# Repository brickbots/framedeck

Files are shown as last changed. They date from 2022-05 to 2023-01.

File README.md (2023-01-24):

# framedeck

A Cyberdeck built with the framework mainboard.  

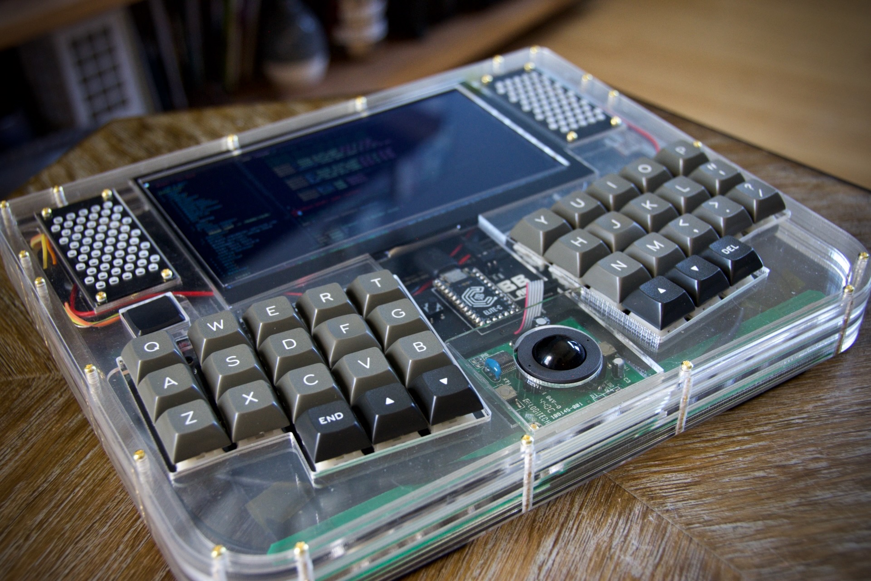
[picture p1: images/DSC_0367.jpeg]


[Framework](https://frame.work) has 
created a really slick, fully user servicable, laptop and have recently started selling the 
[mainboard](https://frame.work/marketplace/mainboards) as a SBC for general 
use.  To better support folks who may want to integrate it into their projects, they are also 
releasing [technical documentation](https://github.com/FrameworkComputer/Mainboard) including 
pinouts, cad models and other resources.

As they were preparing this documentation release, they emailed me to see if I'd be interested
in a collaboration of sorts.  They would provide one of their laptops and some additional modules
for me to build something unique with the only condition being that I released the designs 
for public use.  So here we are!

The mainboard is a great little unit, being a full Intel based system on a single board with 
great storage and memory expansion, decent on-board graphics and full power management.  Since
it was designed to fit into the laptop first and foremost, some of the connectors are fairly
specialized, but with the pinouts available there are a lot of opportunities for expansion. The
board also has four standard USB-C ports which provide many possibilities without even trying
any of the other on-board connectors.

That's all to say that when they reached out and explained thier plans and offered to let 
me play with one, I jumped at the chance and this is what I came up with after some experimentation.

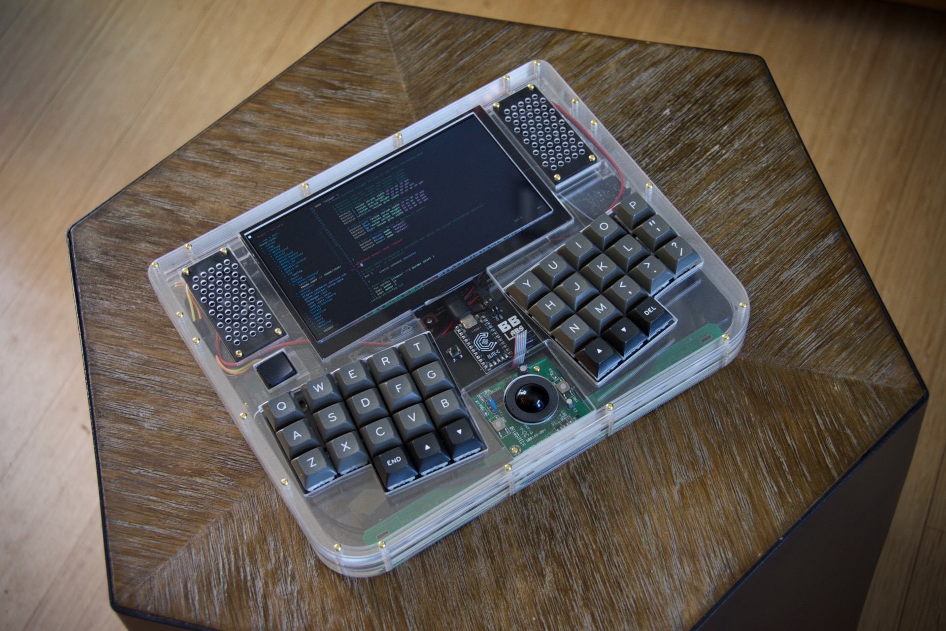
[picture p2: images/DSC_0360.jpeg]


It's my take on the slab style computers that were somewhat popular before the world settled
on clamshell designs for portable computers.  I really wanted a 
[TRS-80 model 100](https://en.wikipedia.org/wiki/TRS-80_Model_100) when I was young so this
sort of design was a big influence.

To complete the unit I added battery from the framework laptop, custom mechanical keyboard, wifi card, 
ssd storage, 16gb of memory, 7" IPS display and some speakers in the hopes of making a fairly useful 
computer.  I ended up using the mainboard with their battery rather than roll my own power solution as
it has solid capacity and is already desinged to work with the onboard power management.  For
other uses the mainboard can be powered via USB-C, so a solid powerbank would provide plenty 
of runtime or it can run off any USB-C power brick for stationary use.

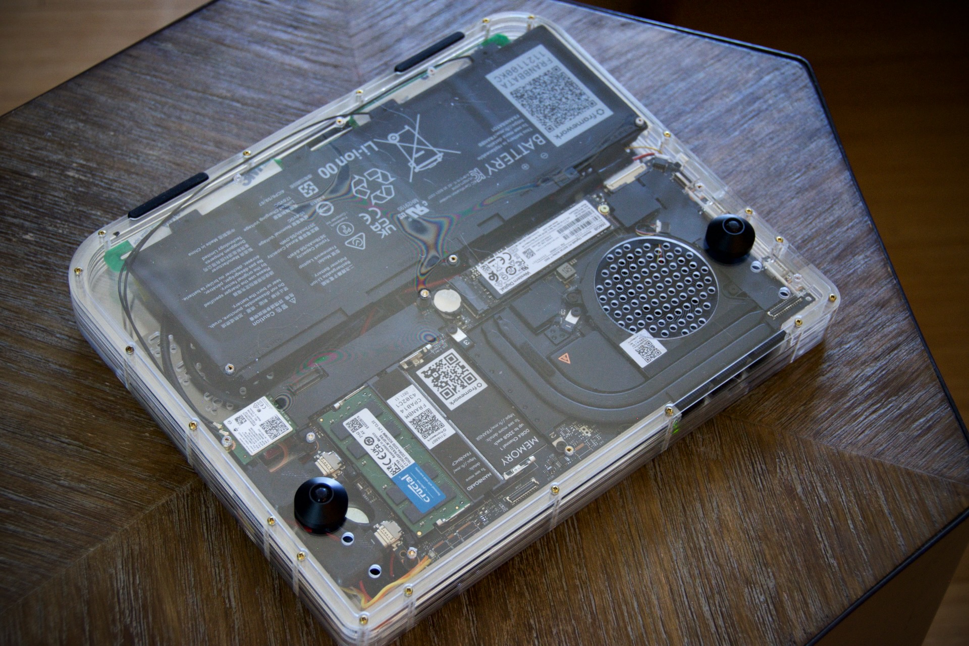
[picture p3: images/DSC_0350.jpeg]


For the case, I wanted something interesting that showed off the mainboard, custom keyboard PCB and 
just looked unusual... so clear acrylic and brass won the day!  I thought about 3d printing, and 
I could have done it in several sections, but building the unit up with layers of laser-cut acrylic 
offered some interesting challenges and opportunities.  

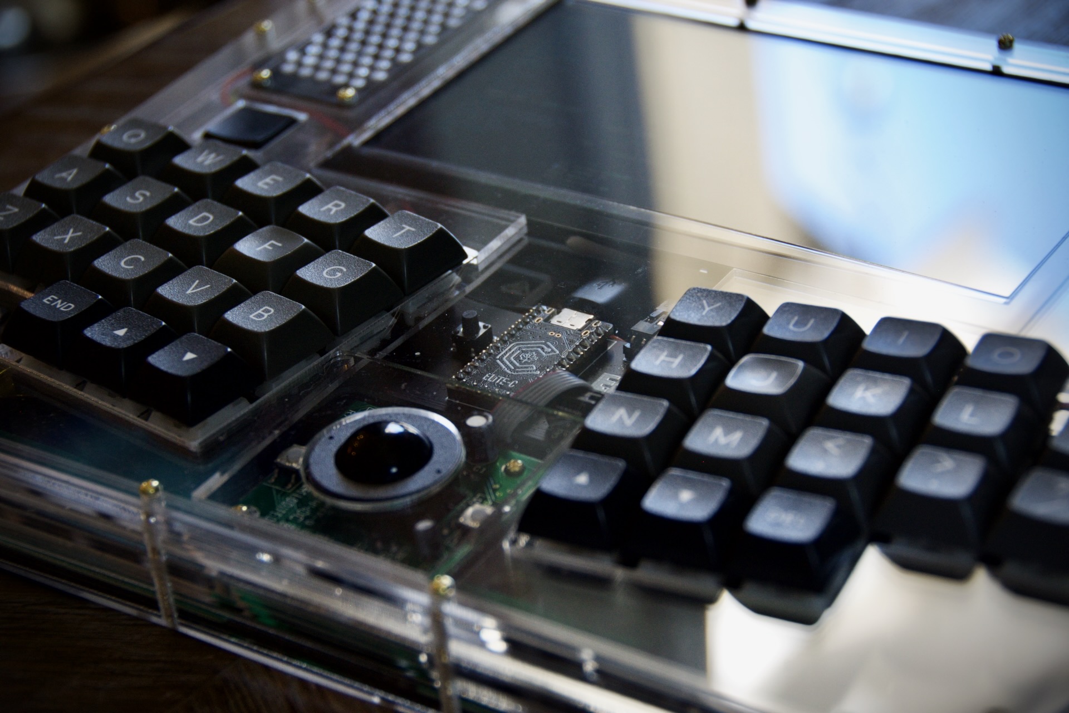
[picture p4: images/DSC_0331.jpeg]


Consider this repo a sort of 'guided tour' to give some inspiration and show what might be done with the
framework mainboard.  I'll highlight some things that I think are interesting, or that were tricky, but 
it's not meant to be a comprehensive guide so all the normal caveats apply if you
want to dive in and build something based off this material.  I'm including all of
my design files for reference, but there are lots of details of the build I probably won't cover.  
If you want to build one, or something similar, feel free to reach out and I'd be happy to answer
and questions or provide advice.

* [Build Tour](docs/build_tour.md)
* [Parts List](docs/parts.md)
* [Case Layers](case/layers.md)
* [3d Printed Bits](printed_parts/bits.md)
* [What's with that keyboard?](docs/keyboard.md)

## Copyright and License

Copyright (c) 2022 Richard Sutherland. All rights reserved.

All files are licensed under MIT license or [CC BY-SA 4.0](https://creativecommons.org/licenses/by-sa/4.0/), see the [LICENSE](LICENSE) for more information.

<a href='https://ko-fi.com/brickbots' target='_blank'>Buy Me a Coffee at ko-fi.com

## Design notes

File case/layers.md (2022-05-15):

# framedeck - layer guide

The acrylic case is built in layers.  I've included DXF files suitable
for laser printing, they use MM as units.  Layers are built in roughly
alphabetical order from the top down, but some layers appear twice and 
may be different thicknesses.

Around the edge of all the layers (except the last one) are holes to 
hold the whole sandwich together.  The A (top) and L (bottom) layers 
have holes sized for M2 screws.  The layers between have holes sized
for M2 standoffs.  You can screw into the standoffs from the top 
and bottom to secure the assembly.  You will need LONG standoffs...
I had to combine a couple to get them long enough.

The bottom two layers are held together with 3mm long M2 heat set inserts.  
Each of the bottom two layers are 1.5mm so the insert neatly joins them
together when inserted through both. They serve to secure the very bottom M 
layer to the bottom L layer and also provide fixing points for the mainboard 
and battery.

Please see this table below for full details of all the layers.  Since the 
actual thickness of cut acrylic will usually vary, you may need to add or 
remove some of the general spacer layers (E/G) or try different thicknesses.
I ended up using all of these as is, with the exception of one of the 'C' layers

## Hardware
Layer|Thickness (MM)|Notes|Image
---|---|---|---
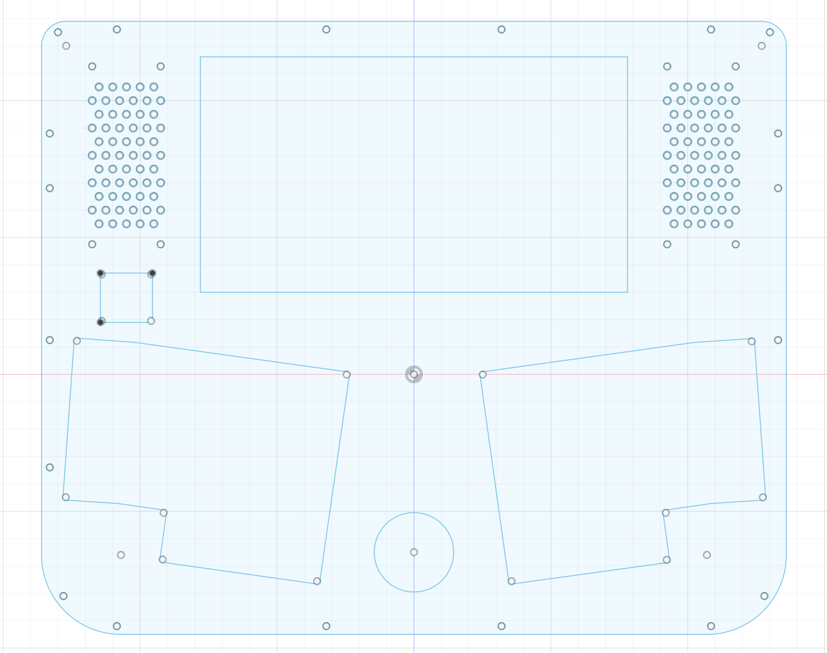
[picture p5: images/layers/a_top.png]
A Layer A
A|1.5|Top|
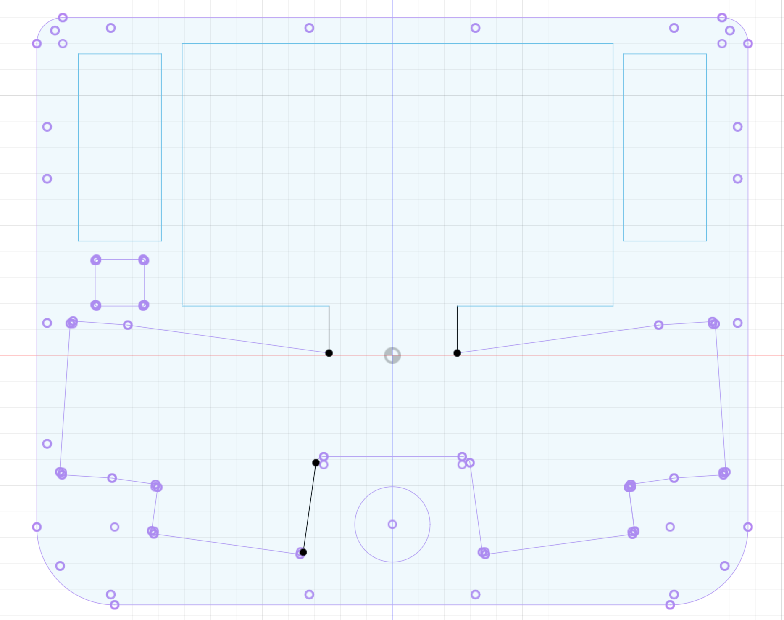
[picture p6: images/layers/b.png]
B Layer B
B|2.0||
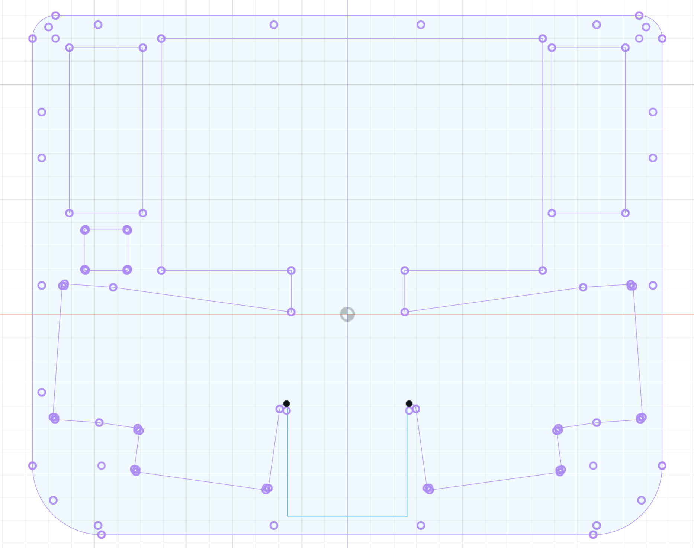
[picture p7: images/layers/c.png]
C Layer C
C (1)|1.5|C layers combined = 2.5mm|
C (2)|1.0|C layers combined = 2.5mm|C Layer C
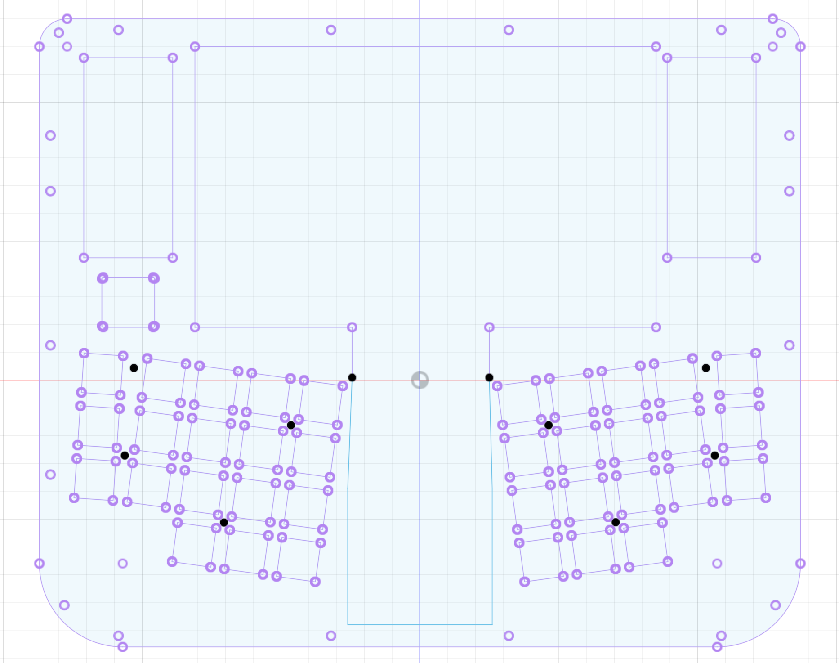
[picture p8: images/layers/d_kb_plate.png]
D Layer D
D|1.5|KB Plate|
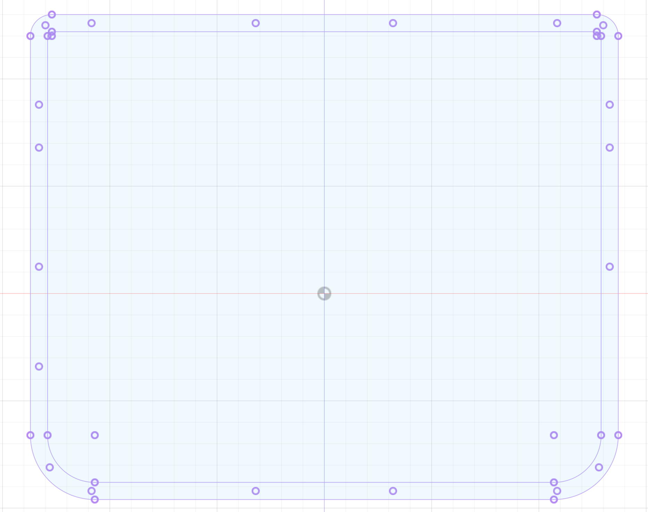
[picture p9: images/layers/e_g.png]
EG Layer E / G
E (1)|1.5| E/G Layers use same file|
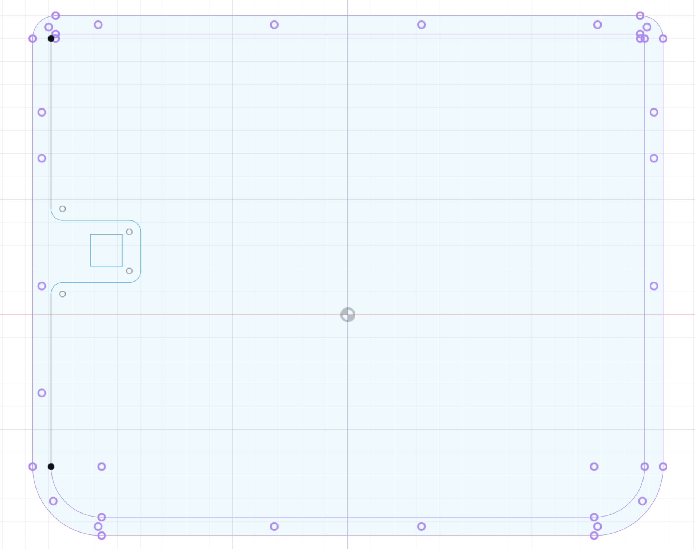
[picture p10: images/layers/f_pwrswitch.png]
F Layer F
F|1.5|Power switch|
G|3.0| E/G Layers use same file|EG Layer E / G
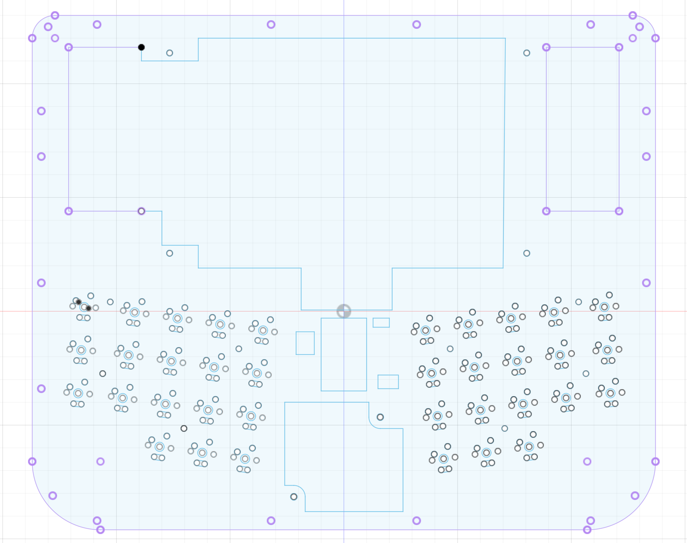
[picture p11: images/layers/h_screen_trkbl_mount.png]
H Layer H
H|3.0||
E (2)|1.5|E/G Layers use same file|EG Layer E / G
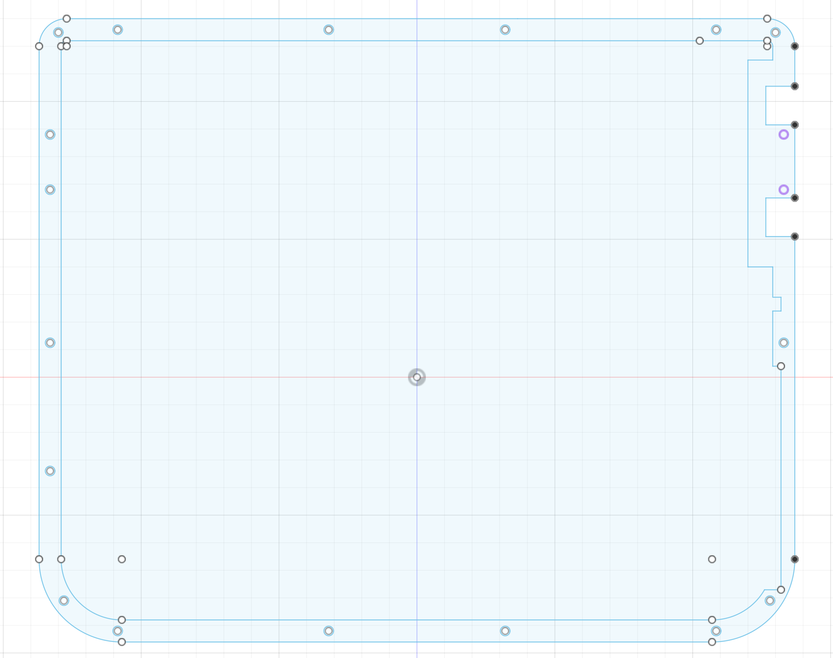
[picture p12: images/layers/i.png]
I Layer I
I|3.0||
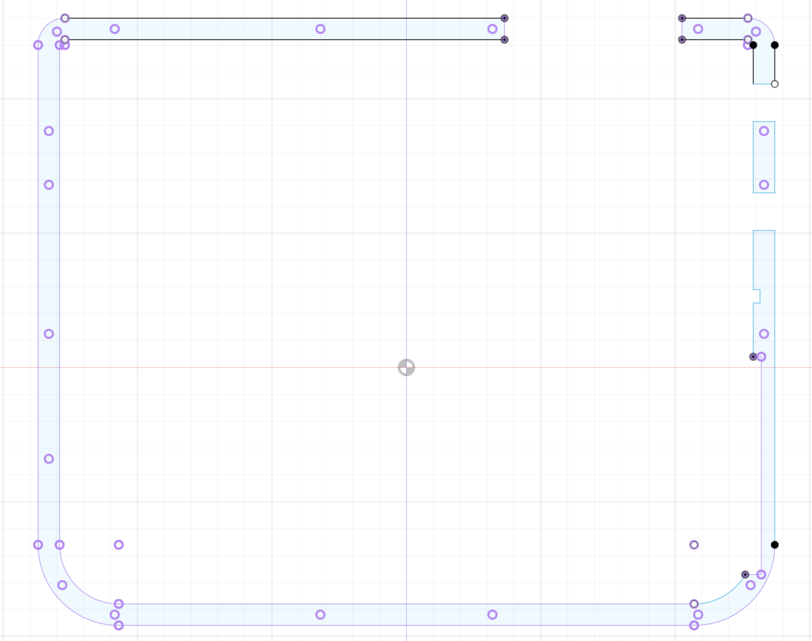
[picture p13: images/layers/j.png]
J Layer J
J (1)|2.0||
J (2)|2.0||J Layer J
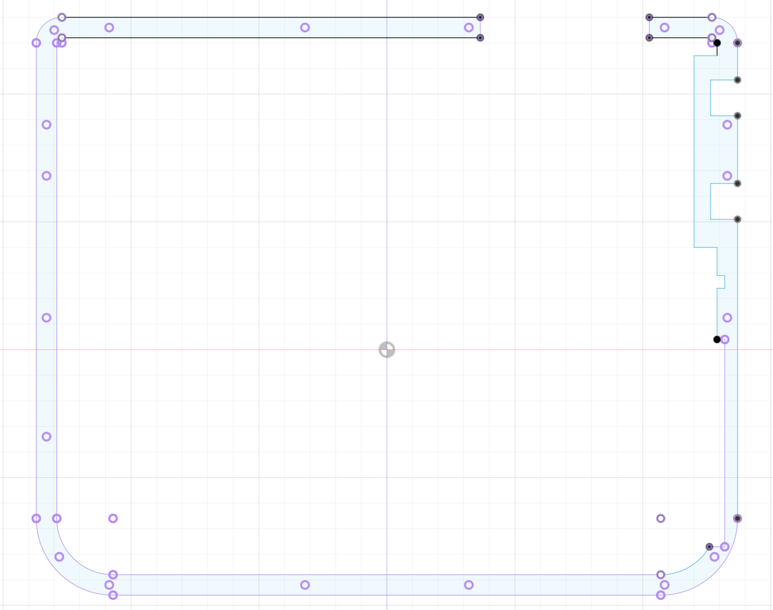
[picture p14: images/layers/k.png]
K Layer K
K|3.0||
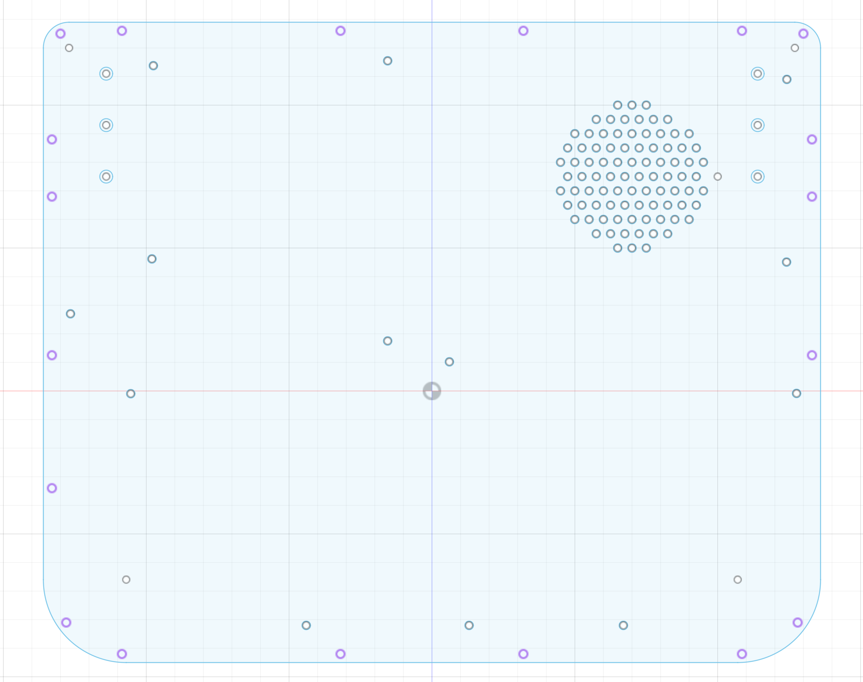
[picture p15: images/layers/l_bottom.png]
L Layer L
L|1.5|Bottom|
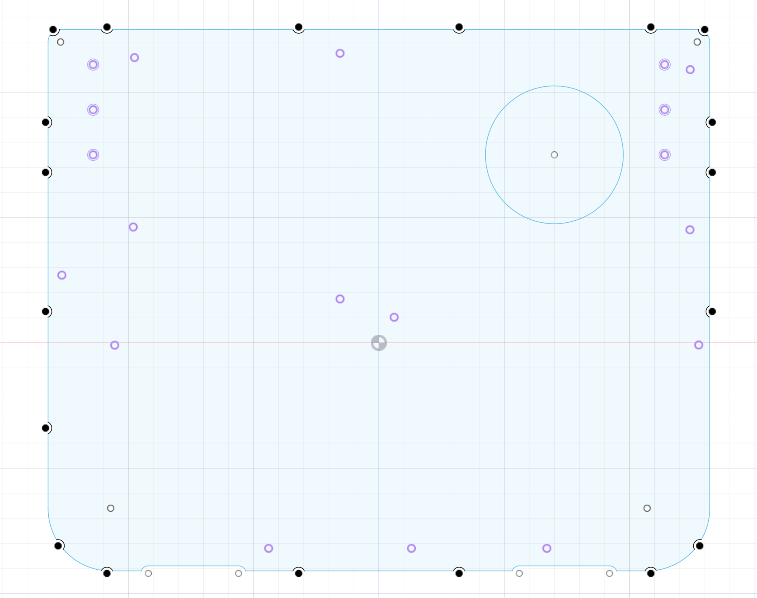
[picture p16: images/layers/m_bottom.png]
M Layer M
M|1.5|Bottom|

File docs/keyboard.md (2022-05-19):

# framedeck - keyboard

The keyboard layout used on the framedeck is something I sort of take for 
granted as it's the one I've been using for quite a while in various
forms.... but it's something that's, understandably, generated a lot of questions!

These usually boil down to either "How do you type with so few keys?" or "Where is 
the [specific key] key?".  Not only is the keyboard on the framedeck light on keys, 
the markings on the keys are not very specific.

## Physical layouts, virtual layouts and layers

Every keyboard has sort of two layouts... how the keys are arranged in space, the 
physical layout, and what each key does when you press it, the logical one.  Most
keyboards indicate what happens when you press a key with the legend on the keycap,
which is pretty handy!  

However, these legends don't often tell the full story.  The
key marked with a 'W' on your keyboard probably generates a 'w', but if you hold the
shift key it generates a 'W'.  Only one of those is probably marked on the key because
this is such a common way to arrange things... but 
sometimes, in the case of numbers, the shifted value is also indicated.  Older computers
might have even more indications for other types of key-combinations....

The general idea is that by pressing a specific key, like shift, all the other keys switch
to another 'layer' and generate something different.  This allows us to generated hundreds of 
symbols with many fewer keys.

In the extreme, you can geneate many, many symbols with very few keys :-)  Most custom 
keyboards run software which is very flexible and allows a lot of options when it comes 
to remapping keys.

## Miryoku

It's surprisingly easy to endlessly tweak the way a keyboard works once you have that 
power.  There are many discussion about finger placement and letter frequency in various
languages, but there is no empirically correct answer, so it's easy to just keep changing 
things, even if you keep the keys in the same positions.  If you also play around with 
varous physical layouts, there is even more to fiddle with.  Each one of these changes 
means some amount of re-learning... so after a year or 
so of tweaking my own layouts (physical and logical) and having to partially re-learn each 
time, I discovered [Miryoku](https://github.com/manna-harbour/miryoku).  It's a much better 
logical layout than I ever came up with and has the amazing benefit of being suported on
top of many, many (almost any!) physical layout.

This last bit was important to me as I had accumlated an embarassing amount of keyboards
and I wanted to be able to use them all without remembering what layout each had been
configured with.

Miryoku Layout

The default letter layout for Miryoku is Colmak-DH, but I configure mine with standard QWERTY. 
One day I really should switch, but for now it's working well for me.  The image above shows all
functions for all the layers, but the website has a much more digestable set of images with 
each layer on it's own. 

## Layer Tap and home-row mods

Almost all smaller keyboards use a system for accessing layers which allow these layer select 
keys (like the shift key on a standard keyboard) to be used for double duty.  If you tap these
keys they generate a specific symbol, such as space or enter, but if you hold it down and press
another key, you get the layer version of the second key.  All the thumb buttons are setup this
way and are the primary way of getting to the various layers in Miryoku, but they also do the 
heavy lifting with often used keys like space, tab, enter, esc, delete, and backspace.o

Shift, Ctrl, Alt, and Mod (Windows/Mac) keys are on the home row and are duplicated on each side
so you can hold down the 'J' key with the left hand and press any key on the right hand for the 
shifted version of that key.

The [Miryoku Docs](https://github.com/manna-harbour/miryoku/tree/master/docs/reference) do a
much better job of explaining this, so give them a read if you are interested!

If you'd like to hear more about my journey with the layout and reducing key counts, check out
[My Miryoku Journey](https://github.com/manna-harbour/miryoku/discussions/60)

Cheers!

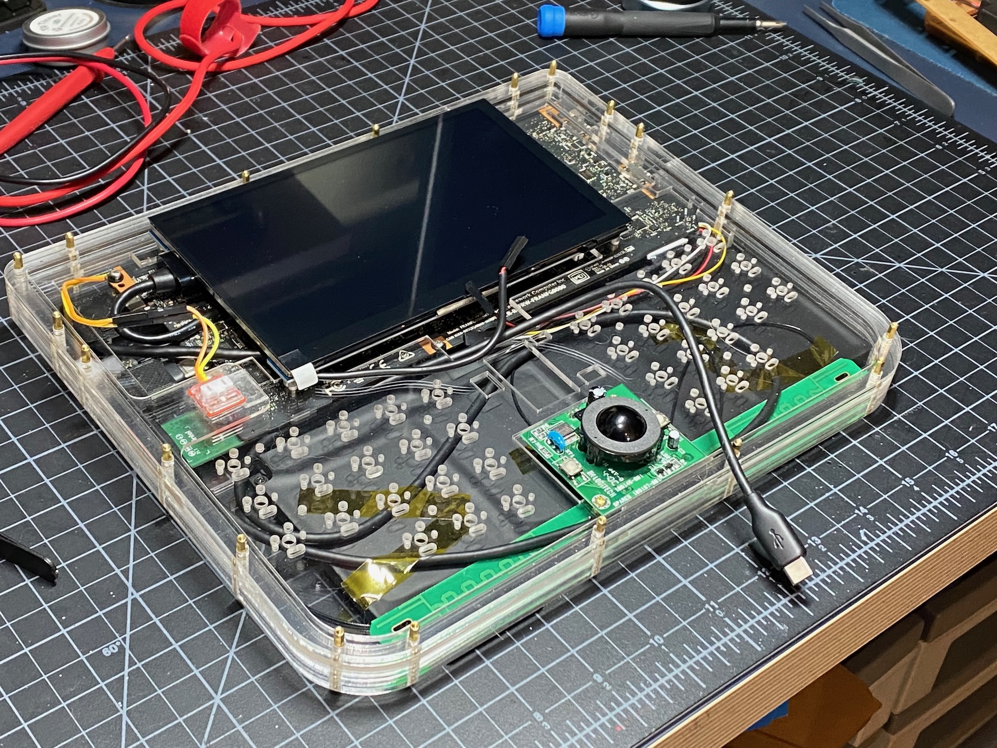
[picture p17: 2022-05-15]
images/power_switch.jpeg

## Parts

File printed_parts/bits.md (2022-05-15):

# framedeck - printed parts

Here are STL's for the M2 to mainboard adapters plus the cable enclosures for 
the right-angle USB-C hdmi and keyboard cable.

The mainboard adapaters need two for each screw to sandwich the mainboard between them.
For the right-angle adapter, you can mirror for the other half and trim to length.  I
filled mine with epoxy to serve as strain relief and hold the two halves together.

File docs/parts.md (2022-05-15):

# framedeck - Parts List

This is not a comprehensive parts list.  You'll need lots of M2 hardward, wires and 
likely some other bits to build a complete copy of the framedeck.  This list is 
more for refence of some of the specific items I selected.

## Electronics
Quantity|Item|URL
---|---|---
1|framework mainboad| https://frame.work/marketplace/mainboards
1|framework battery| https://frame.work/products/battery
1|M2 compatible Wifi board| https://frame.work/products/intel-wi-fi-6e-ax210-vpro
1|Compatible Wifi antenna| https://www.amazon.com/gp/product/B08T8F3GDT/
1|M2 compatible NVMe storage| 
1|DDR4 SO-DIMM| 
1|Logitech 161A keyboard mouse trackball board mouse board T-SBC12-CP|https://www.aliexpress.com/item/1005001942167314.html
1|7" HDMI IPS Display|https://www.amazon.com/gp/product/B08H8HZRLQ
1|USB-C to HDMI cable|https://www.amazon.com/gp/product/B083KQNHQH/
1|Set of speakers|https://www.adafruit.com/product/1669

## Keyboard
Quantity|Item|URL
---|---|---
1|Keyboard PCB| /gerbers/framedeck_kb_gerbers.zip
1|6 x 6mm x 7mm PCB Momentary Switch 4 Pin DIP|
36| MX style switches|
36| 1N4148 SMT SOD-123 Diodes|
1|Elite-C Microcontroller.  Required for extra pins|

## Misc
Quantity|Item|URL
---|---|---
2|Rubber Feet - SKUFs!| https://keeb.io/products/skuf-silicone-rubber-keyboard-feet 
2|Raised KB conical feet, M3 screws| https://www.amazon.com/gp/product/B07WRPTTBV

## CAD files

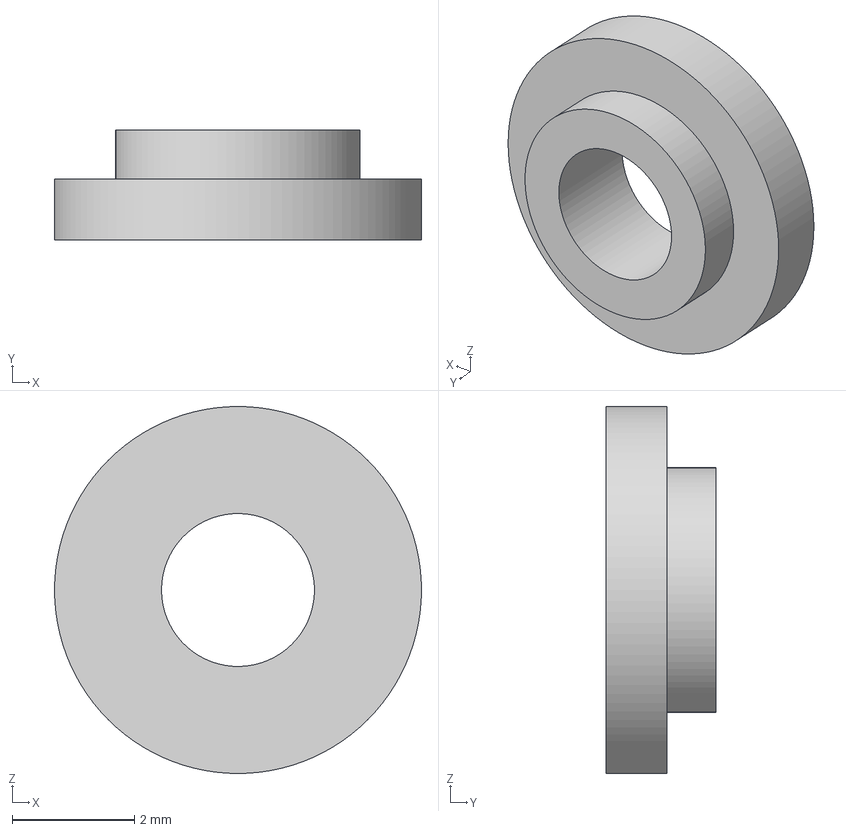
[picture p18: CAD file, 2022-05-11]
printed_parts/mainboard_mount.3mf
6.00 x 1.80 x 6.00 mm

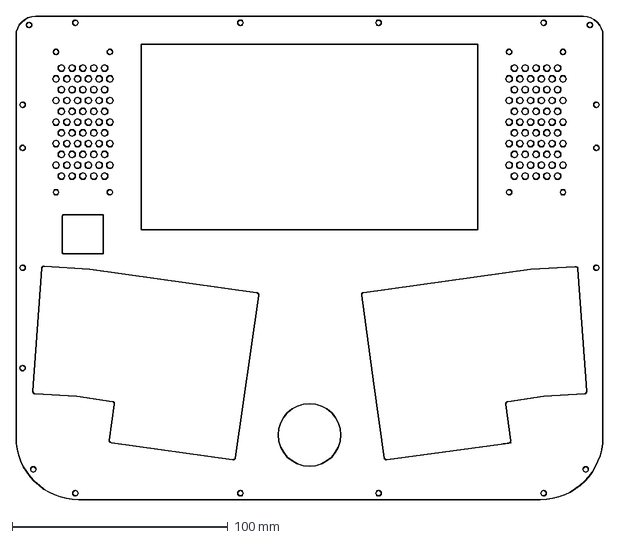
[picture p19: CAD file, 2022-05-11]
case/framedeck_case_A.dxf
272.0 x 224.0 mm

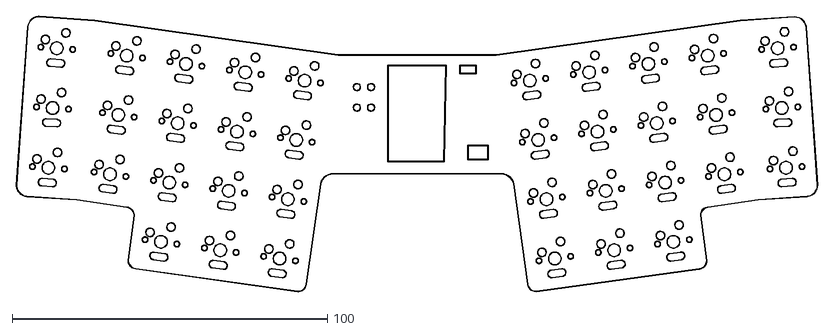
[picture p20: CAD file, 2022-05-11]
kicad/framedeck_kb/framedeck_kb-B_Adhes.dxf
254.2 x 87.3

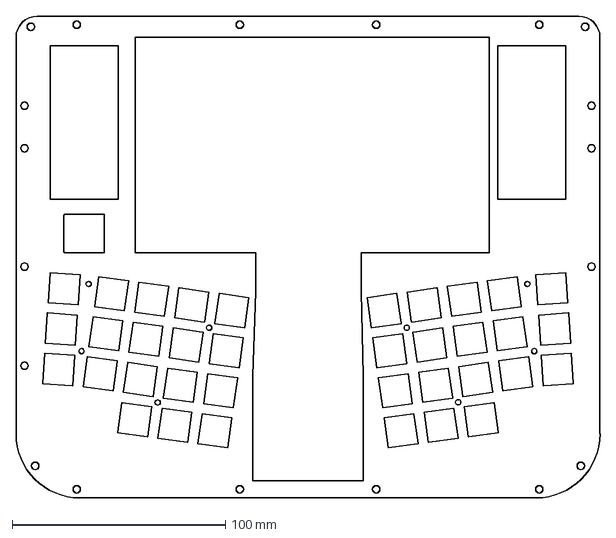
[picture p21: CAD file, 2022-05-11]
case/framedeck_case_D.dxf
274.0 x 226.0 mm

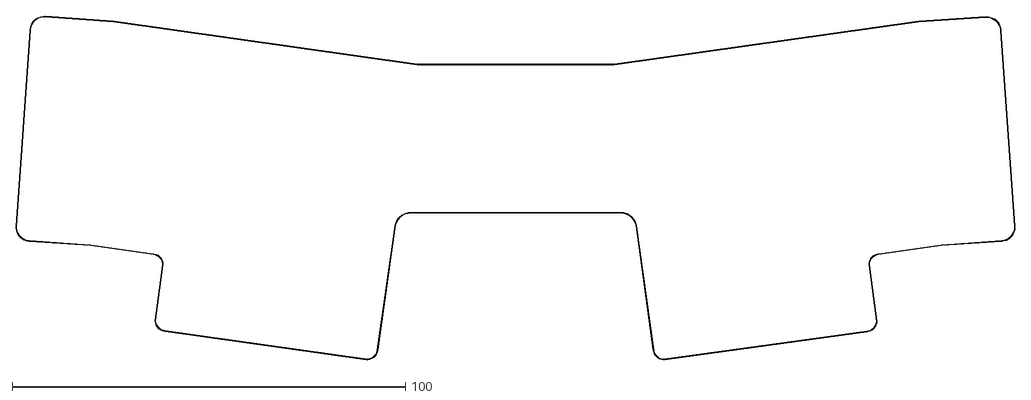
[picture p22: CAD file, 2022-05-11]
kicad/framedeck_kb/framedeck_kb-Edge_Cuts.dxf
254.2 x 87.3

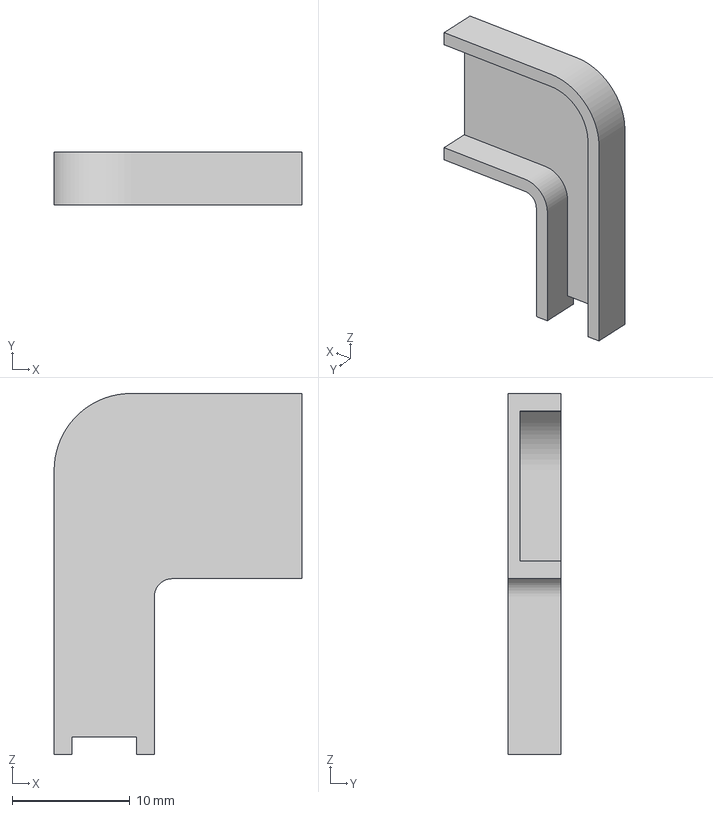
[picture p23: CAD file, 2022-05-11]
printed_parts/ra_cable_guide.3mf
21.0 x 4.50 x 30.6 mm

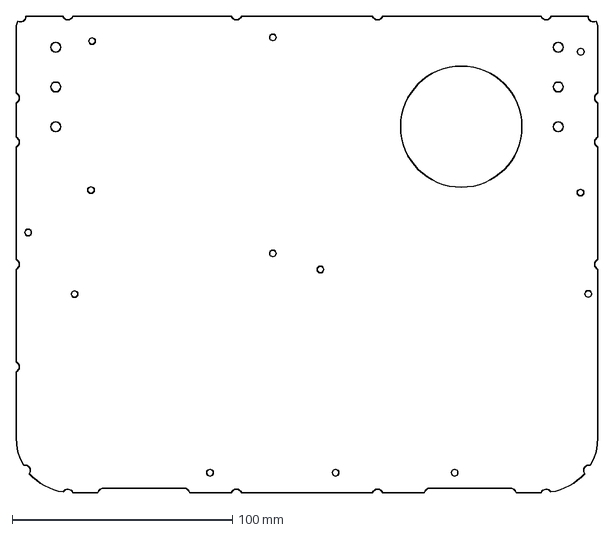
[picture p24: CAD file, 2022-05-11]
case/framedeck_case_M.dxf
264.0 x 216.0 mm

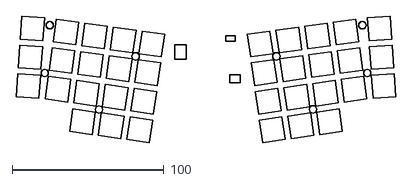
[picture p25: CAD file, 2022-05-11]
kicad/framedeck_kb/framedeck_kb-F_CrtYd.dxf
250.0 x 83.2

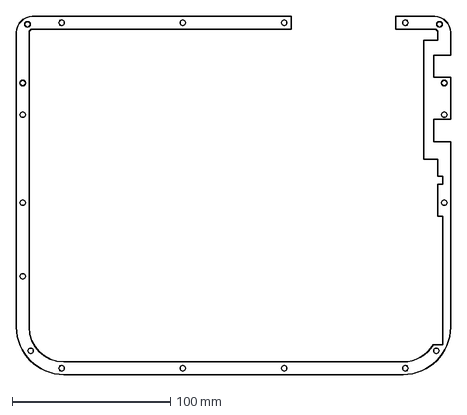
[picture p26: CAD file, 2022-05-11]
case/framedeck_case_K.dxf
274.0 x 226.0 mm

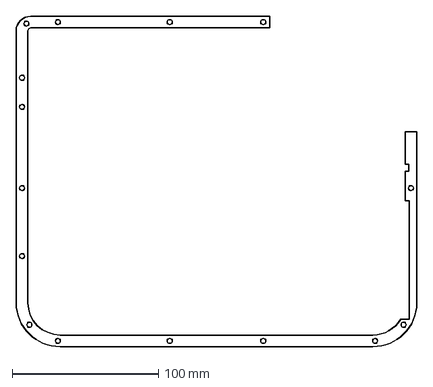
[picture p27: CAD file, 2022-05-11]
case/framedeck_case_J1.dxf
274.0 x 226.0 mm

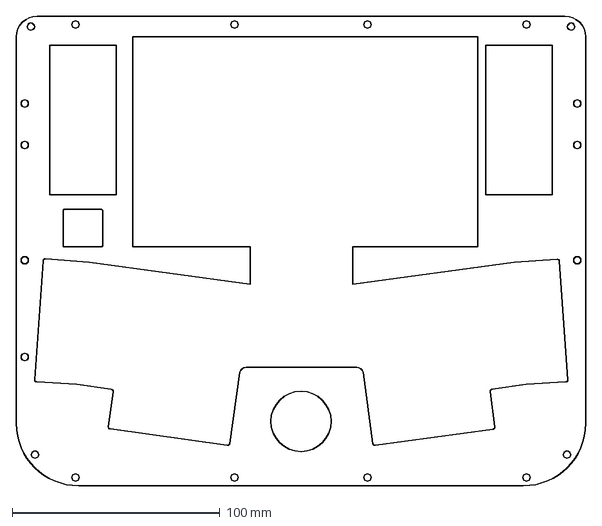
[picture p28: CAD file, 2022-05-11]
case/framedeck_case_B.dxf
274.0 x 226.0 mm

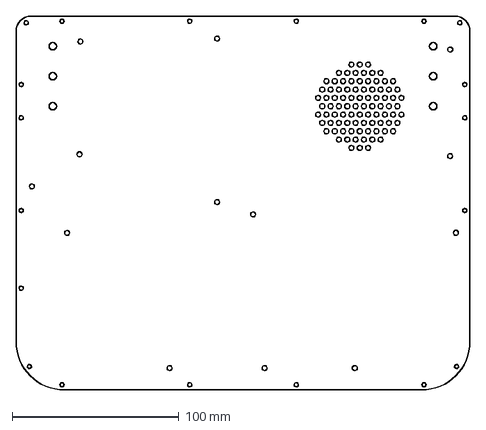
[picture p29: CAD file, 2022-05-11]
case/framedeck_case_L.dxf
272.0 x 224.0 mm

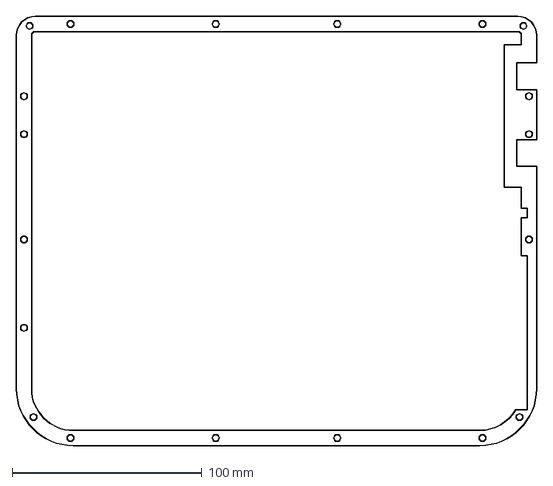
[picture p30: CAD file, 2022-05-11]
case/framedeck_case_I.dxf
274.0 x 226.0 mm

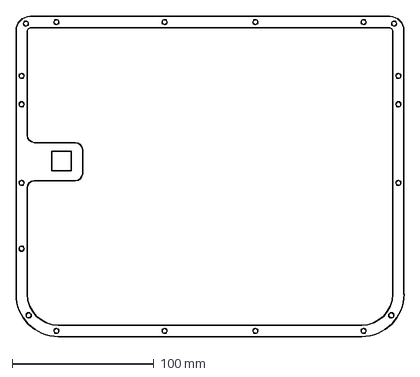
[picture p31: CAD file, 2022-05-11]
case/framedeck_case_F.dxf
274.0 x 226.0 mm

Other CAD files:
case/framedeck_case_EG.dxf
case/framedeck_case_H.dxf
case/framedeck_case_J2.dxf
case/framedeck_case_C.dxf
case/framedeck_case_J3.dxf

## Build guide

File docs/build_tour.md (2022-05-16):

# framedeck - Build Tour

This is not intended to be a full guide, more an inspirational look 
at the build process.  You can review the [Parts list](../docs/parts.md)
to get oriented.  I took all of these photos with my phone as I was building 
so the quality and lighting vary a fair bit.  If you are hoping to build 
something similar and have questions, please reach out and I'd be happy to
answer them!

## Overview
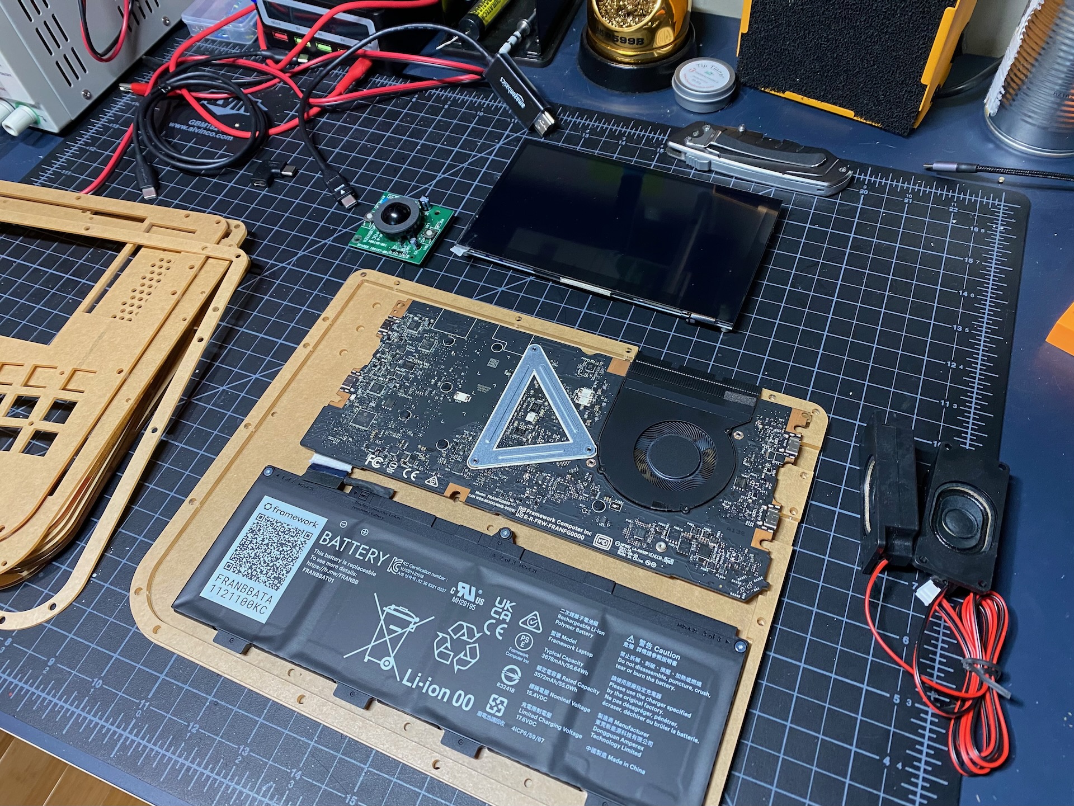
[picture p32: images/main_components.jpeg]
Main Components

This image shows most of the main components.  The only big thing missing here
is the custom keyboard PCB.  The case is built up from [layers](../case/layers.md) of laser cut acrylic 
of various shapes.  As the stack is built from bottom to top, various components 
are affixed to the acrylic pieces as they are layered on. 

There are four main groupings of layers where particular items attach.

## Mainboard and Battery
The two bottom layers are held together with heat-set inserts.  The layers are 1.5mm each and 
the inserts are 3mm, so they can extend through both layers and secure them together.  This 
also provides the mounting points for the battery and mainboard.  

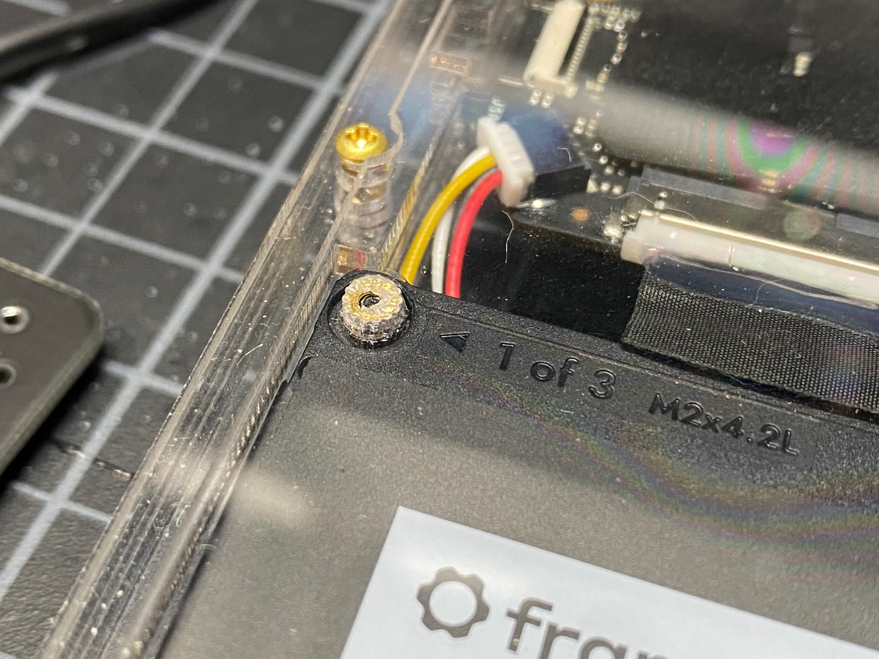
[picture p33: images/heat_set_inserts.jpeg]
inserts


Here you can see the placement of the mainboard and battery... but in this test fitting session I
installed the battery in the wrong orientation.  I decided to install the mainboard and battery
'upside down' so they would be fully visible from the bottom of the unit.  The mainboard is 
correctly oriented but the battery connector is on the wrong side and the middle mountpoint 
doesn't line up.  This photo does show the small notch in some of the lower layers to 
accomidate the battery.  It has to sit just so in relation to the mainboard as the connector
is short and rather stiff.

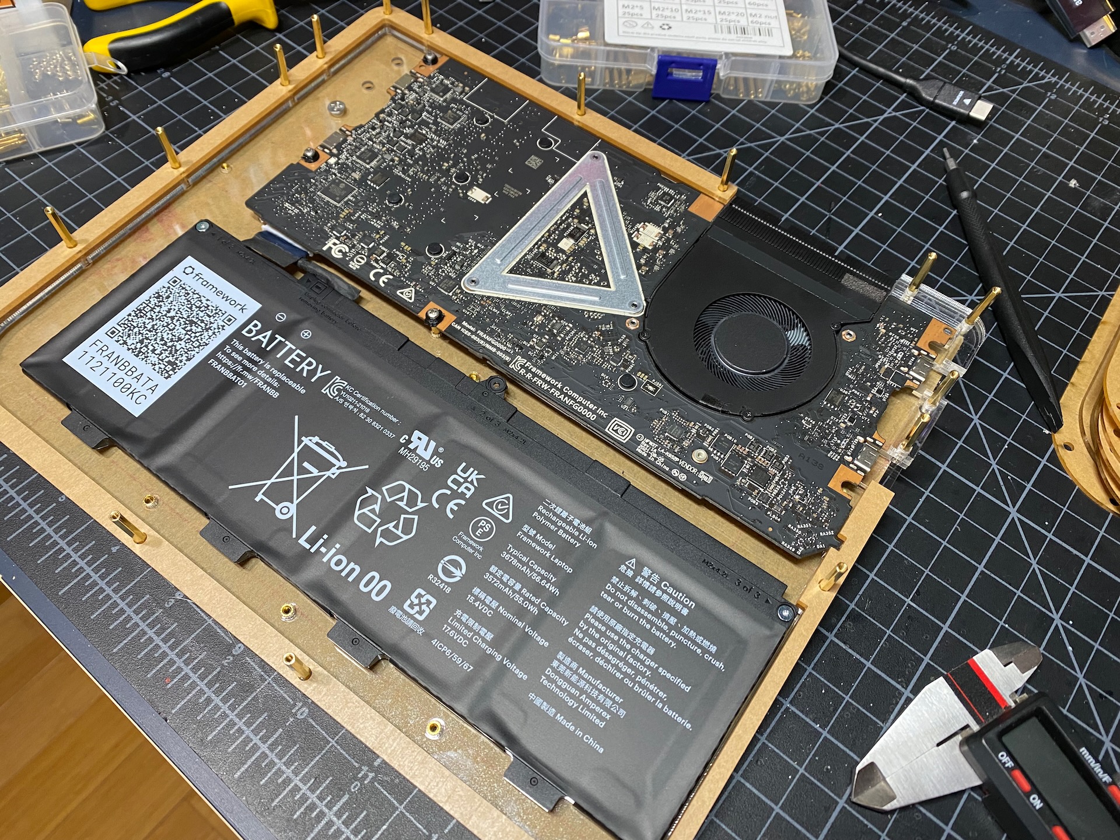
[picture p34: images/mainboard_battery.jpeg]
mainboard and battery


I stuck with M2 hardware generally, but had to print up little adapters to fit the larger
mainboard mounting points.  

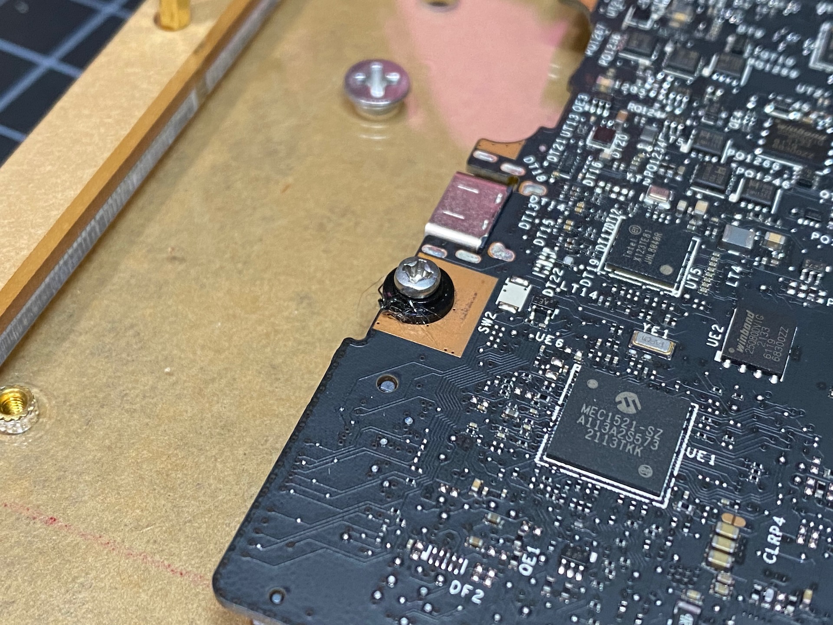
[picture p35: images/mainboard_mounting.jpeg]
mainboard mounting


This bottom 'unit' consists of layers M-I and sandwiches the available USB ports between layers
of acrylic.  It's difficult to see from this photo, but there is acrylic under the USB ports and 
a matching layers sits on top.  Here you can also see the long stand-offs required to sandwich
all the layers together.

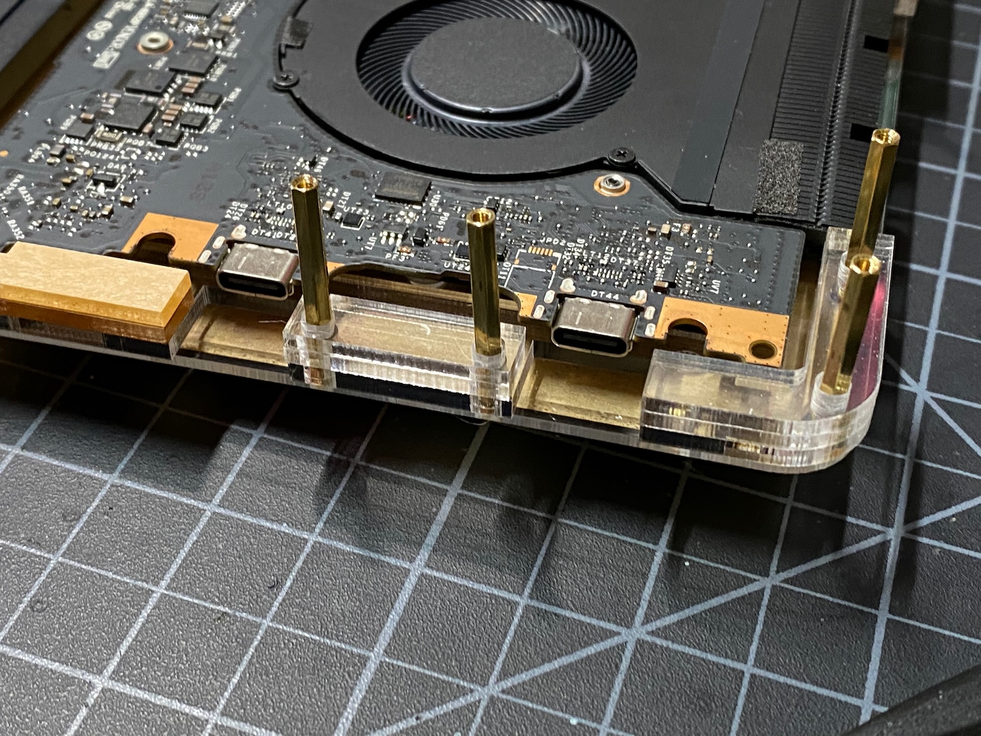
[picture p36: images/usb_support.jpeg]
usb support


This portion of the unit also has the wifi card (plugged into the mainboard), wifi antenna 
(green PCB's at the front of the case),
speaker wires plugged into the mainboads, and some custom made right-angle usb-c connectors 
which are fully enclosed and run the screen and keyboard.  The top is a USB-C to hdmi cable 
and the bottom is a USB-C to USB-C to
plug into the keyboard microcontroller.  Below you can see some of the cable management and 
all the pieces ready to be covered with subsequent layers

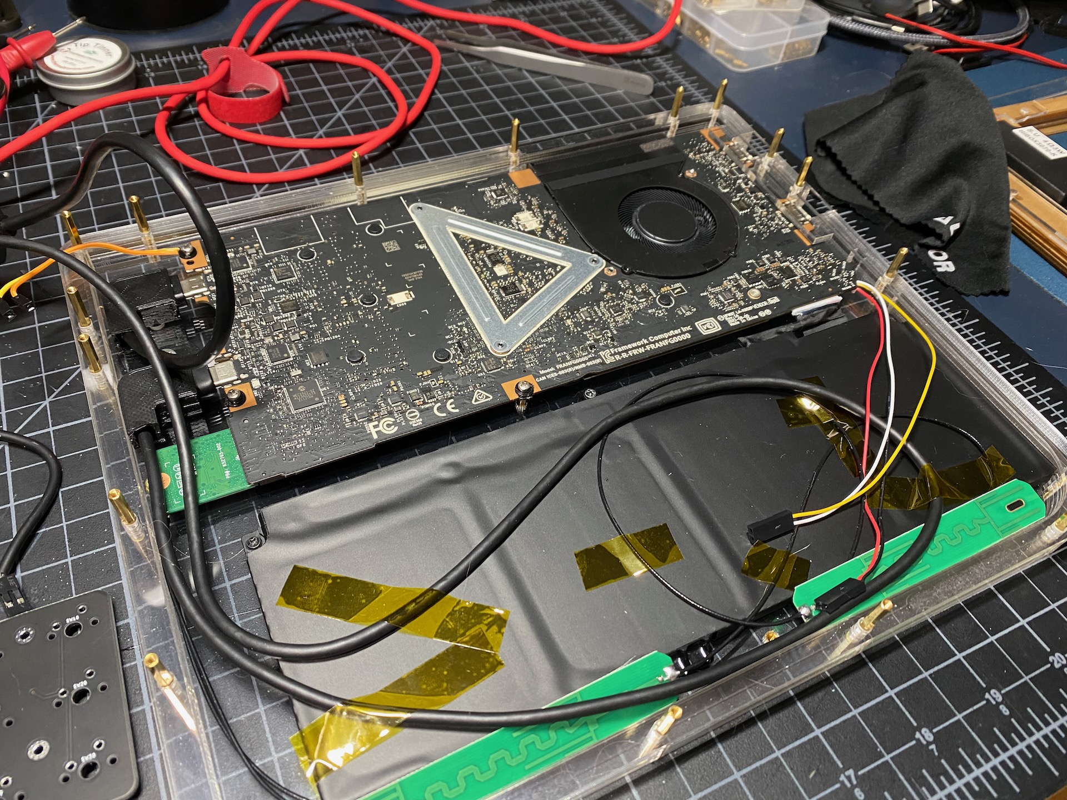
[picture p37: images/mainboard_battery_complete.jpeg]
mainboard complete


Finally, here's a shot of the bottom of the unit with the mainboard and battery presented.  This
also shows the ventilation holes in the case for the mainboard fan.  It vents out the back of the
unit through a nice heatsink assembly which all comes with the mainboard.  Also visible are the 
repositionable conical feet for the back and the low-profile SKUF feet in the front.  This 
provides a bit of a typing angle and makes the screen a little easier to see.

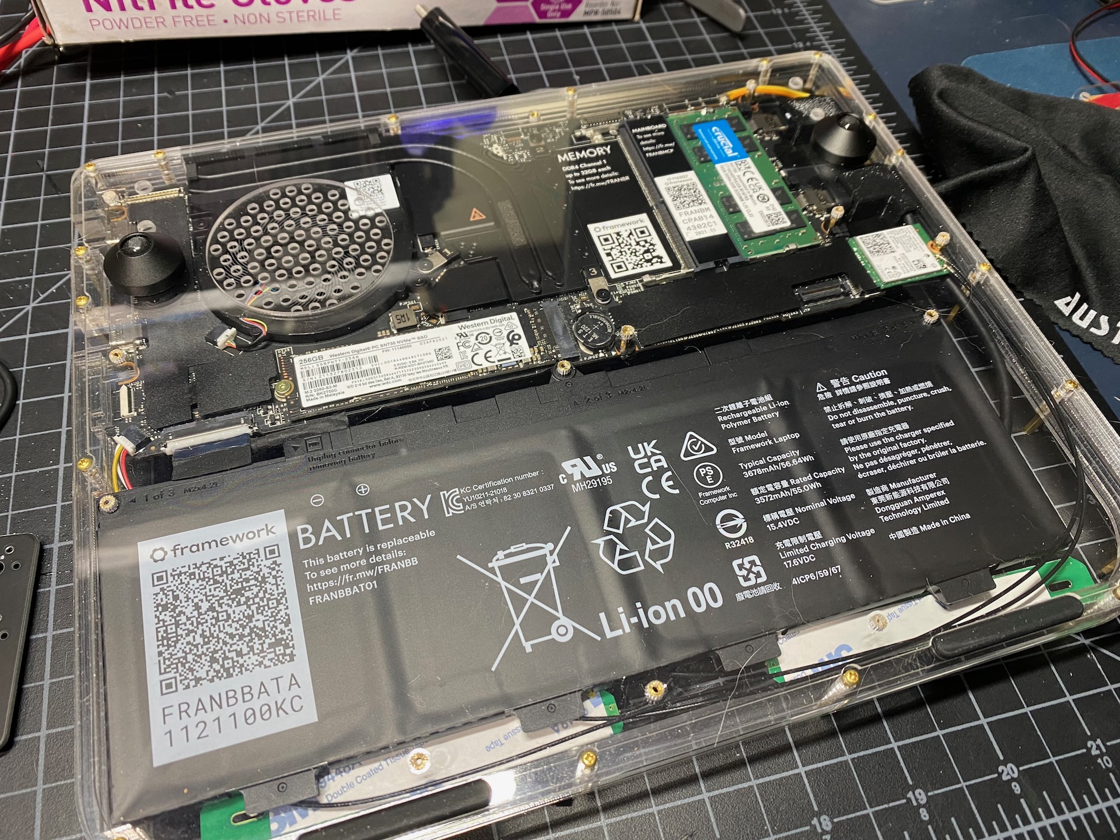
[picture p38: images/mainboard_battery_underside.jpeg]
underside


## Screen, Trackball and Power switch

A couple spacer 'E' layers go on top of the bottom assembly and then we get to layer 'H' which
supports the screen and trackball.  They both mount on top of this 3mm layer and secured with 
screws.  The screen has it's own stand-offs and the trackball just has mounting holes.  

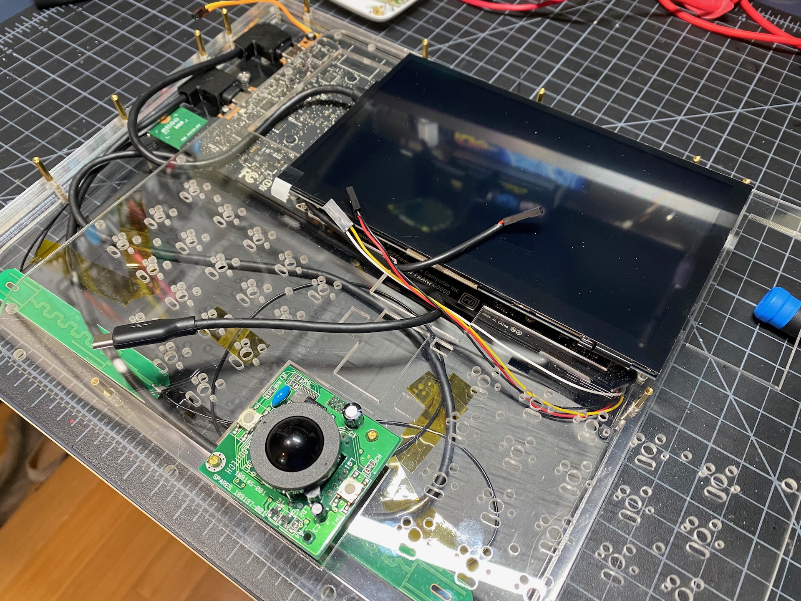
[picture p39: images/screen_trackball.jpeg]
screen and trackball


I didn't get a better photo of this piece, but there is not much to the assembly except screwing 
the two components to the layer and adding in the required cables.  The monitor gets the HDMI end
of the USB-C to HDMI cable and a micro-USB cable with a dupont connector on the other end to get
power from the keyboard PCB.  It's not pictured above, but the trackball gets a six position ribbon
cable plugged into the header underneath.

Layer 'H' also has cutouts for clearance with the keyboard PCB.  I wasn't sure how close they might
actually sit so I used the same trick as my [slabv](https://github.com/brickbots/slabv) and included
clearance cutouts for all the components.  

There is a spacer layer next, and then the layer that holds the power switch ('F').  This switch 
is a choc low profile momentary switch and it connects via some dupont plugs to a wire soldered on
the footprint for the onboard power switch of the mainboard which I removed.  

## Keyboard and Trackball (again)

The next major assemlby is keyboard.  It uses a custom PCB with an elite-C microcontroller.  This 
provides the interface from the key matrix and trackball to the mainboard.  The custom PCB also 
has a power header connected to the raw USB pins of the elite-C which provides power for the 
LCD panel.

Here's a shot of the assembled PCB, without switches, showing the trackball connected and the power
header.  For more information about building up the PCB, see my 
[slabv](https://github.com/brickbots/slabv) repo.

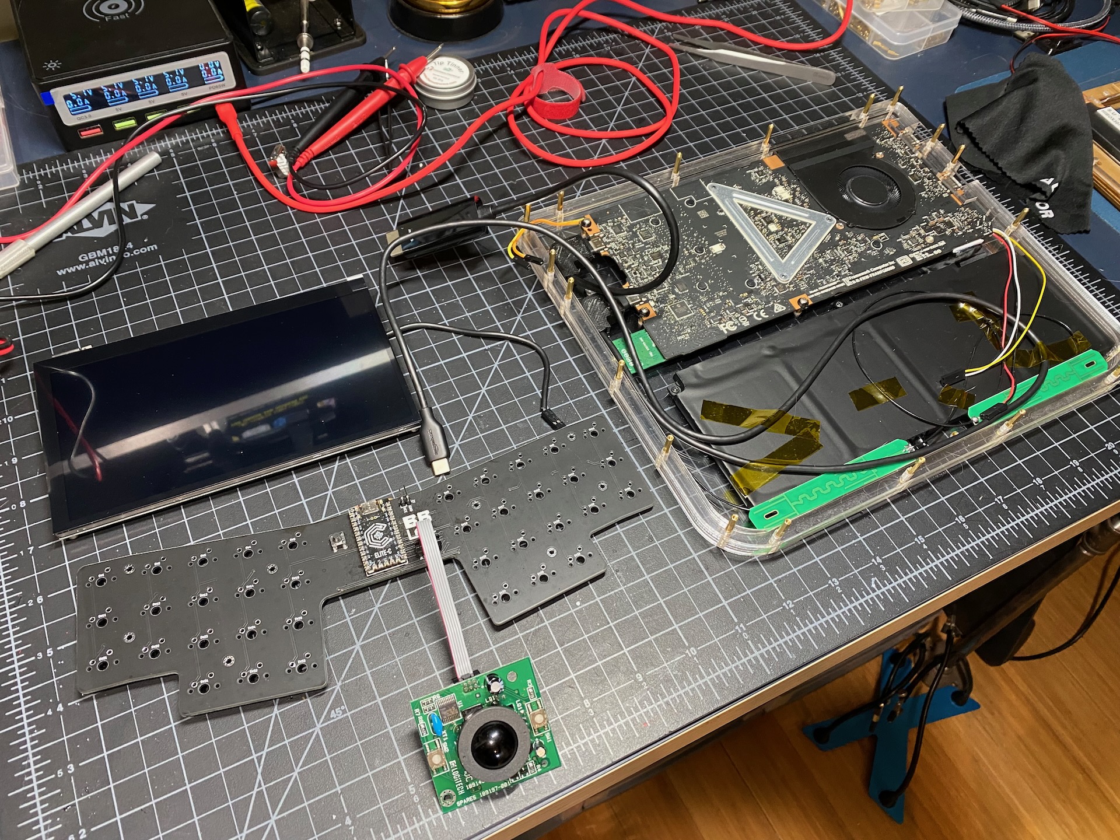
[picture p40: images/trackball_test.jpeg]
trackball test


Layer 'D' serves as the plate for the keyboard.  It is fastened to the PCB using 3mm standoffs, the
switches (Gazzew Boba U4 Silents) get inserted and soldered to the PCB.

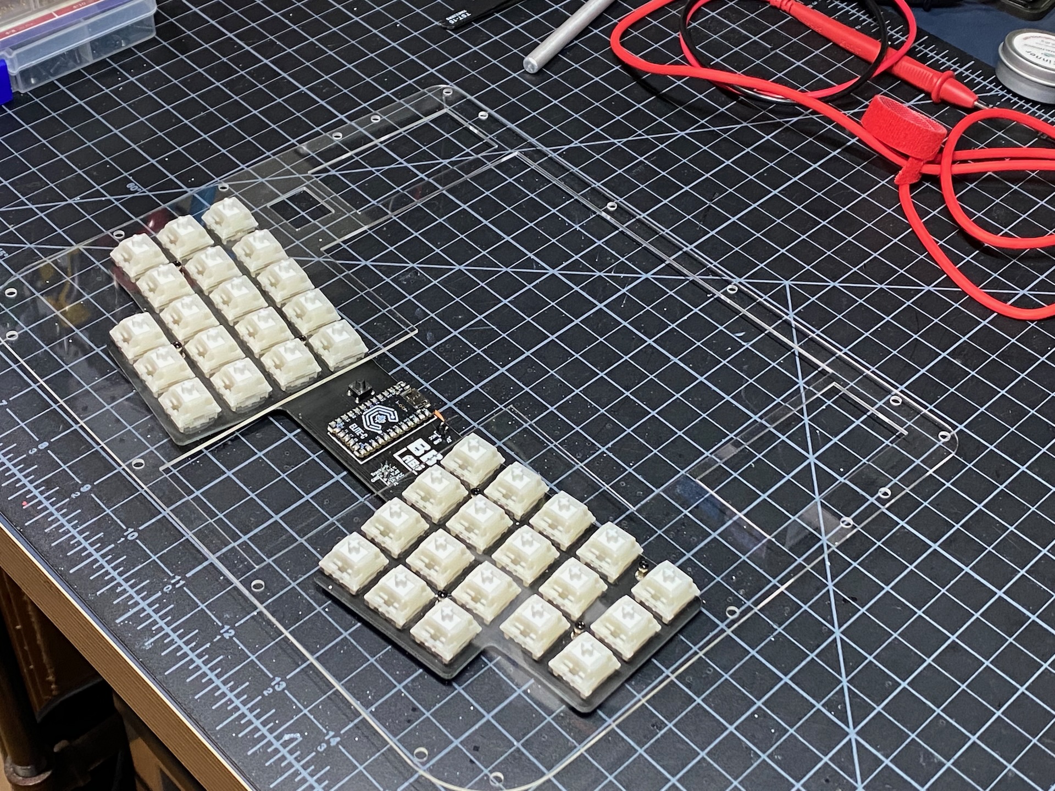
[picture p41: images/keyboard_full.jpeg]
keyboard full


Here's a detail showing the power and trackball header along with the MCU and reset switch.

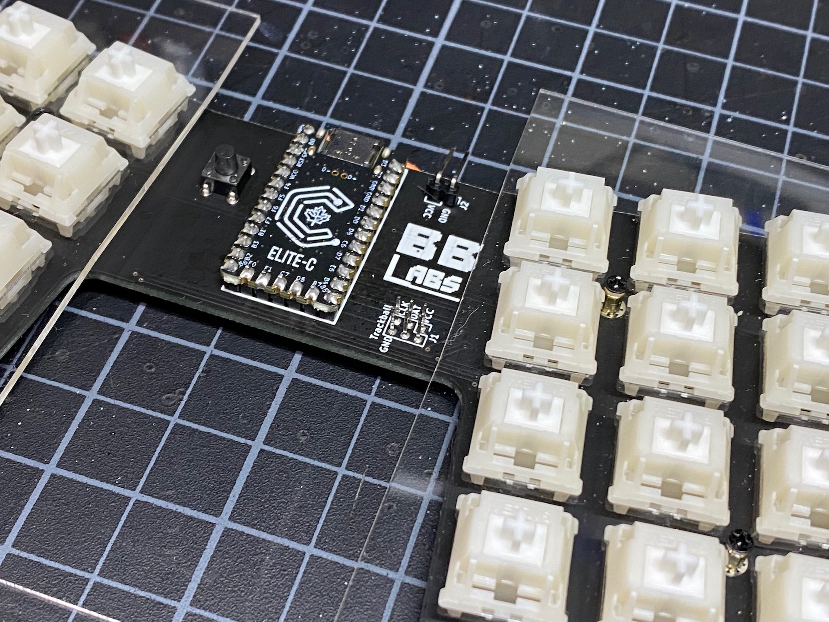
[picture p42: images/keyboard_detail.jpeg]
keyboard detail


As this layer is installed the USB-C cable, trackball cable and power for the monitor need to be
connected.  It's all a tight fit!

## Top and speakers

The last few layers make up the keyboard and trackball surround and hold the two speakers on
either side of the screen.  Here you can see them from the underside, already mounted to the 
'A' layer which serves as the top of the unit.

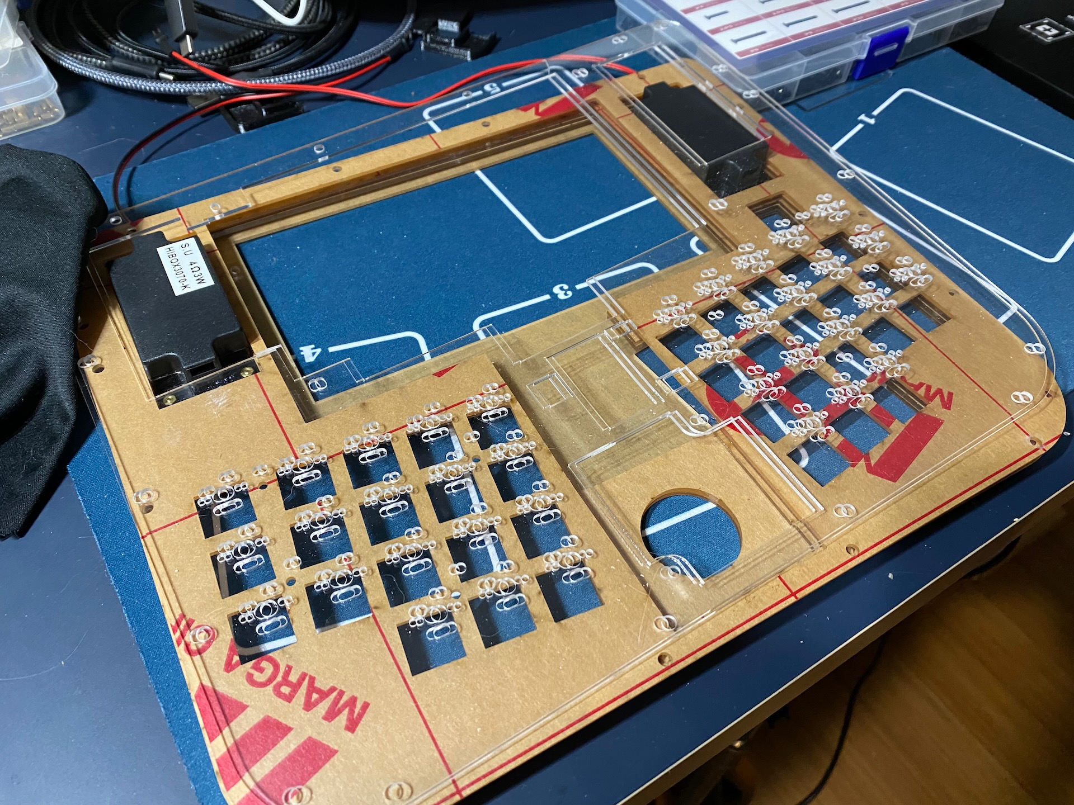
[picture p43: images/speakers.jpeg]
speakers


Here's the whole thing assembled with all the protective film taken off.  The routing of all the 
cables takes some care and the top layer is secured with screws to the stand offs

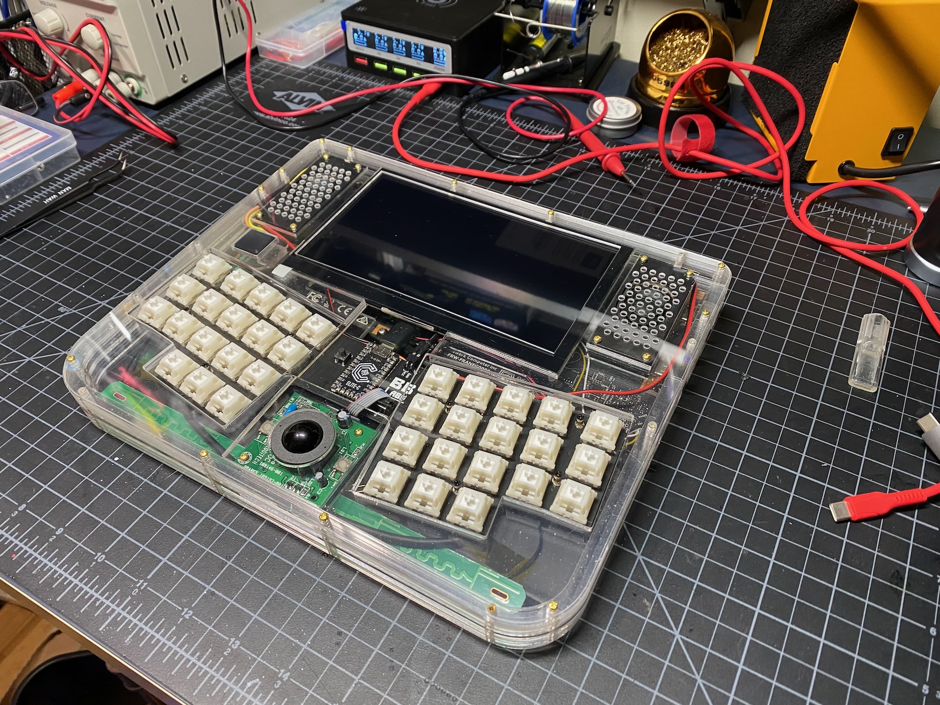
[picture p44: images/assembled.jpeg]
assembled


And finally with keycaps and fully working with Fedora 35

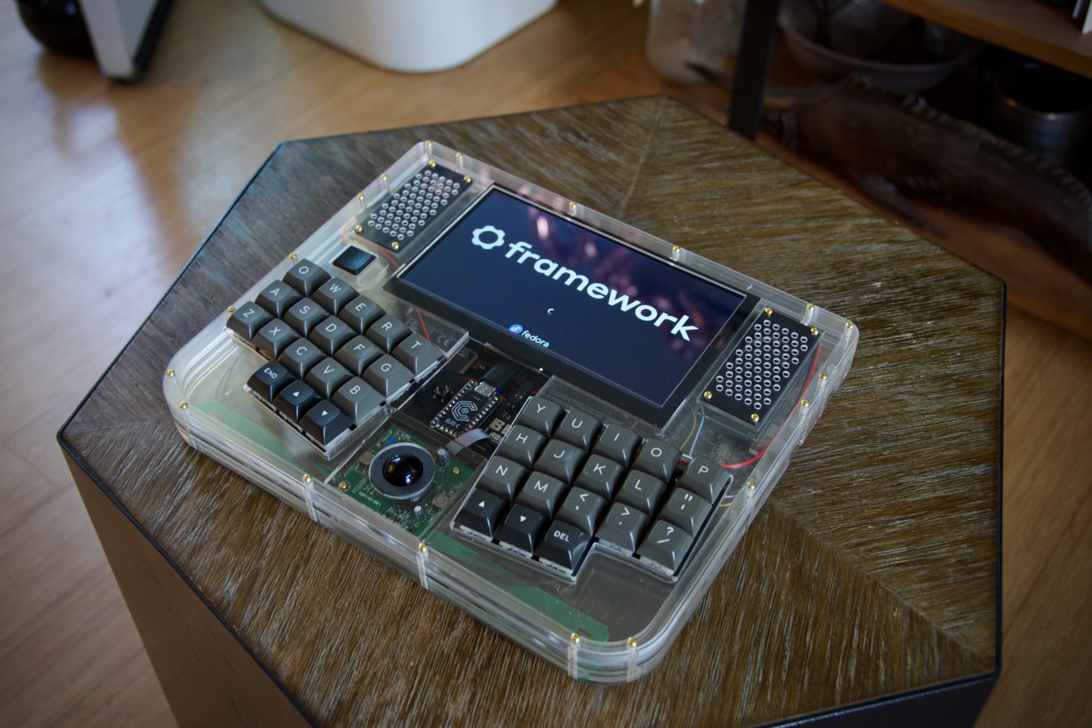
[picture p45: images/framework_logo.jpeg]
booting


## Thanks

Thanks for coming along on this tour.  If you have any questions or would like to build something 
similar feel free to reach out.  If you do build something based on the info in this repo, I'd love
to see it!

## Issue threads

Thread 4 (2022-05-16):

how long this device work?

xor256, 2022-05-16:
A week or month?
I need device with working time twice or more than normal laptop

brickbots, 2022-05-16:
I've not run the battery out fully yet, but I'd expect it to last a bit less time than the actual framework laptop.  I suspect the HDMI panel I'm using + keyboard MCU + trackball are probably less power efficient than the specific panel, keyboard and trackpad used in the framework laptop.

It's hard to get that sort of runtime out of any computing device that runs quickly, but you could get there with some low-power ARM systems perhaps if you didn't need a quite as much performance.

Closed 2022-05-16.

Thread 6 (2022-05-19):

How do you access missing keys such as RETURN or SPACE

larsblumberg, 2022-05-19:
This looks awesome! How do you press ENTER or SPACE though? Does the keyboard use virtual layers that you switch between?

brickbots, 2022-05-19:
Hi @larsblumberg!  Thanks for checking out my repo and for the great question.  It inspired me to add some information about the keyboard here:

https://github.com/brickbots/framedeck/blob/main/docs/keyboard.md

Hopefully this helps answer some of your questions, but the short of it is that the 6 keys along the bottom have legends which don't match their function.  Enter is the left hand inner thumb button and space is the right hand middle.

With smaller layouts like this one, it can be tricky to find keycaps that have the right word or symbol on them, so I often just pick ones that look good.

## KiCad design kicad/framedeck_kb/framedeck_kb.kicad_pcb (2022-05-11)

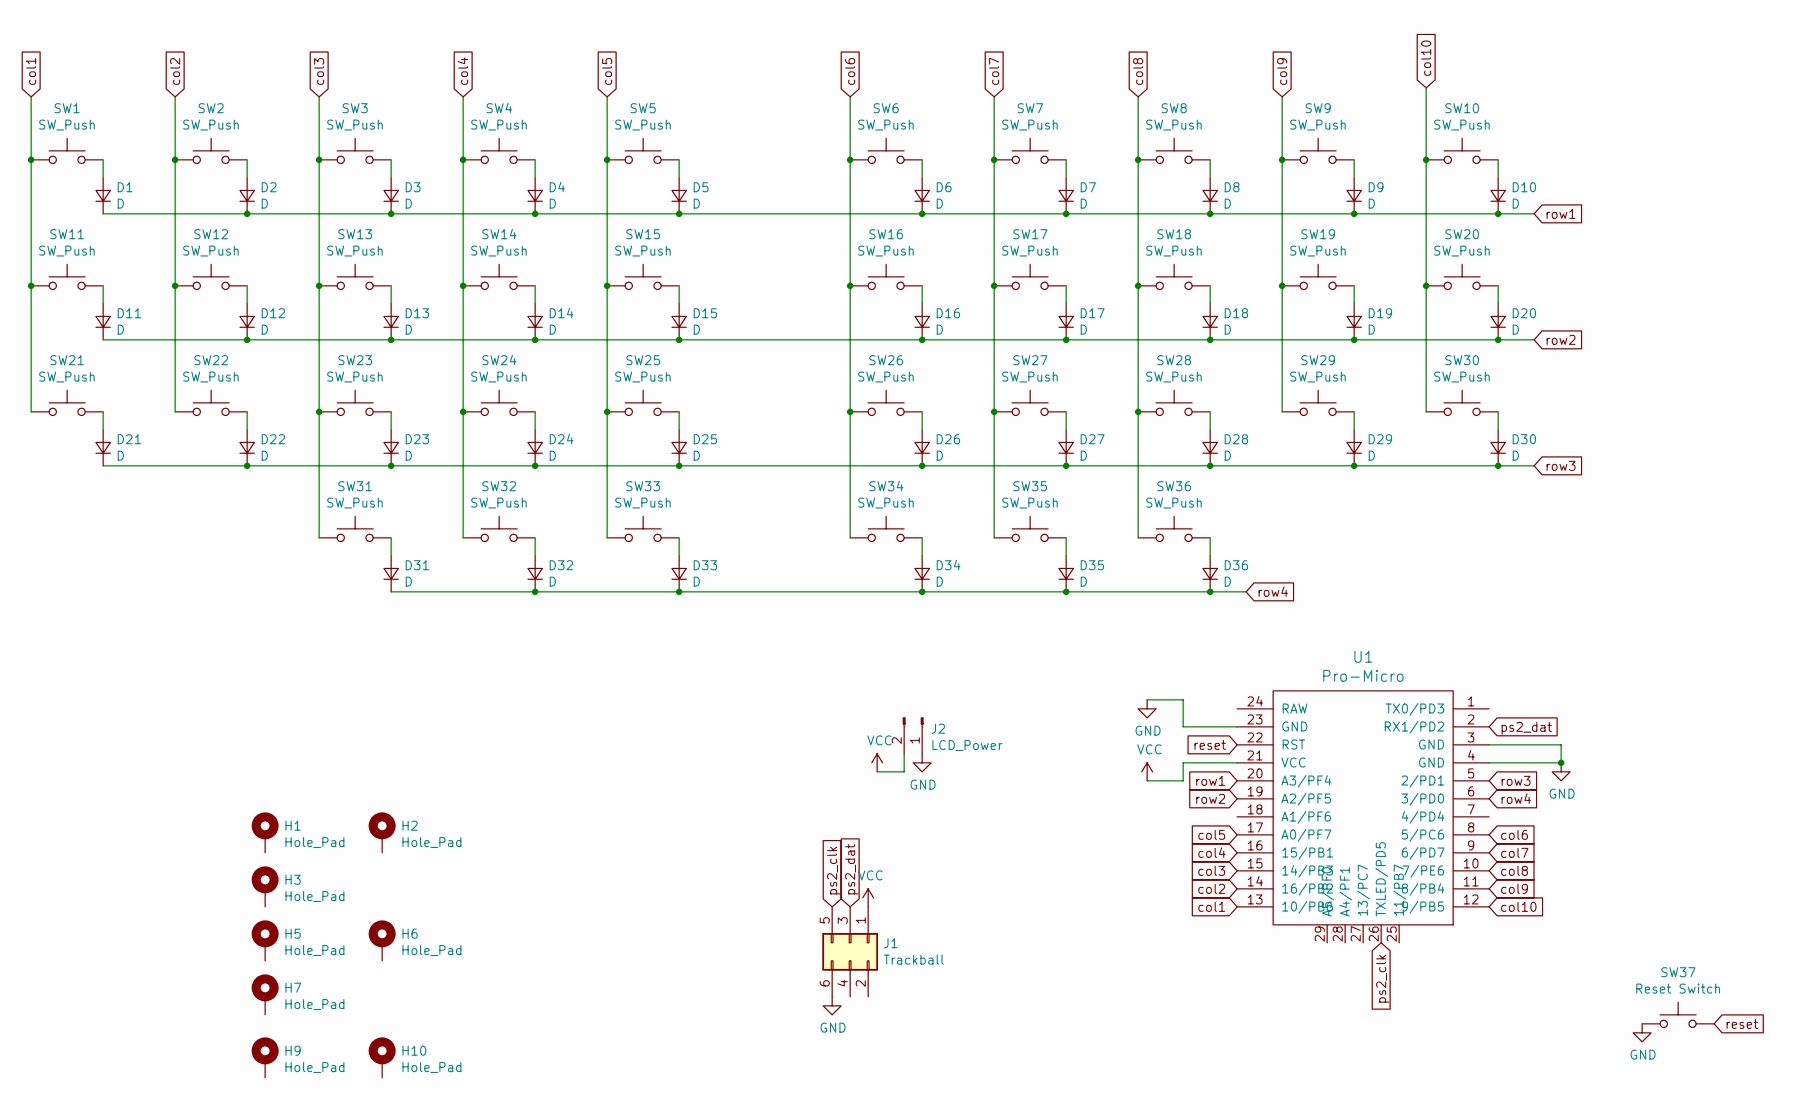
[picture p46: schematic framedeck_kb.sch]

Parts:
D1, D2, D3, D4, D5, D6, D7, D8, D9, D10, D11, D12, D13, D14, D15, D16, D17, D18, D19, D20, D21, D22, D23, D24, D25, D26, D27, D28, D29, D30, D31, D32, D33, D34, D35, D36: D; D_SOD-123
H1, H2, H3, H5, H6, H7, H9, H10: Hole_Pad; Mount_M2
J1: Trackball; PinHeader_2x03_P2.00mm_Vertical
J2: LCD_Power; PinHeader_1x02_P2.54mm_Vertical
SW1, SW2, SW3, SW4, SW5, SW6, SW7, SW8, SW9, SW10, SW11, SW12, SW13, SW14, SW15, SW16, SW17, SW18, SW19, SW20, SW21, SW22, SW23, SW24, SW25, SW26, SW27, SW28, SW29, SW30, SW31, SW32, SW33, SW34, SW35, SW36: SW_Push; SW_MX_plate
SW37: Reset Switch; SW_Push_6mm
U1: Pro-Micro; Elite-C

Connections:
GND: J1.6, J2.1, SW37.1, U1.3 (GND), U1.4 (GND), U1.23 (GND)
unnamed: D1.2 (A), SW1.2
unnamed: D2.2 (A), SW2.2
unnamed: D3.2 (A), SW3.2
unnamed: D4.2 (A), SW4.2
unnamed: D5.2 (A), SW5.2
unnamed: D6.2 (A), SW6.2
unnamed: D7.2 (A), SW7.2
unnamed: D8.2 (A), SW8.2
unnamed: D9.2 (A), SW9.2
unnamed: D10.2 (A), SW10.2
unnamed: D11.2 (A), SW11.2
unnamed: D12.2 (A), SW12.2
unnamed: D13.2 (A), SW13.2
unnamed: D14.2 (A), SW14.2
unnamed: D15.2 (A), SW15.2
unnamed: D16.2 (A), SW16.2
unnamed: D17.2 (A), SW17.2
unnamed: D18.2 (A), SW18.2
unnamed: D19.2 (A), SW19.2
unnamed: D20.2 (A), SW20.2
unnamed: D21.2 (A), SW21.2
unnamed: D22.2 (A), SW22.2
unnamed: D23.2 (A), SW23.2
unnamed: D24.2 (A), SW24.2
unnamed: D25.2 (A), SW25.2
unnamed: D26.2 (A), SW26.2
unnamed: D27.2 (A), SW27.2
unnamed: D28.2 (A), SW28.2
unnamed: D29.2 (A), SW29.2
unnamed: D30.2 (A), SW30.2
unnamed: D31.2 (A), SW31.2
unnamed: D32.2 (A), SW32.2
unnamed: D33.2 (A), SW33.2
unnamed: D34.2 (A), SW34.2
unnamed: D35.2 (A), SW35.2
unnamed: D36.2 (A), SW36.2
VCC: J1.1, J2.2, U1.21 (VCC)
col1: SW1.1, SW11.1, SW21.1, U1.13 (10/PB6)
col2: SW2.1, SW12.1, SW22.1, U1.14 (16/PB2)
col3: SW3.1, SW13.1, SW23.1, SW31.1, U1.15 (14/PB3)
col4: SW4.1, SW14.1, SW24.1, SW32.1, U1.16 (15/PB1)
col5: SW5.1, SW15.1, SW25.1, SW33.1, U1.17 (A0/PF7)
col6: SW6.1, SW16.1, SW26.1, SW34.1, U1.8 (5/PC6)
col7: SW7.1, SW17.1, SW27.1, SW35.1, U1.9 (6/PD7)
col8: SW8.1, SW18.1, SW28.1, SW36.1, U1.10 (7/PE6)
col9: SW9.1, SW19.1, SW29.1, U1.11 (8/PB4)
col10: SW10.1, SW20.1, SW30.1, U1.12 (9/PB5)
ps2_clk: J1.5, U1.26 (TXLED/PD5)
ps2_dat: J1.3, U1.2 (RX1/PD2)
reset: SW37.2, U1.22 (RST)
row1: D1.1 (K), D2.1 (K), D3.1 (K), D4.1 (K), D5.1 (K), D6.1 (K), D7.1 (K), D8.1 (K), D9.1 (K), D10.1 (K), U1.20 (A3/PF4)
row2: D11.1 (K), D12.1 (K), D13.1 (K), D14.1 (K), D15.1 (K), D16.1 (K), D17.1 (K), D18.1 (K), D19.1 (K), D20.1 (K), U1.19 (A2/PF5)
row3: D21.1 (K), D22.1 (K), D23.1 (K), D24.1 (K), D25.1 (K), D26.1 (K), D27.1 (K), D28.1 (K), D29.1 (K), D30.1 (K), U1.5 (2/PD1)
row4: D31.1 (K), D32.1 (K), D33.1 (K), D34.1 (K), D35.1 (K), D36.1 (K), U1.6 (3/PD0)

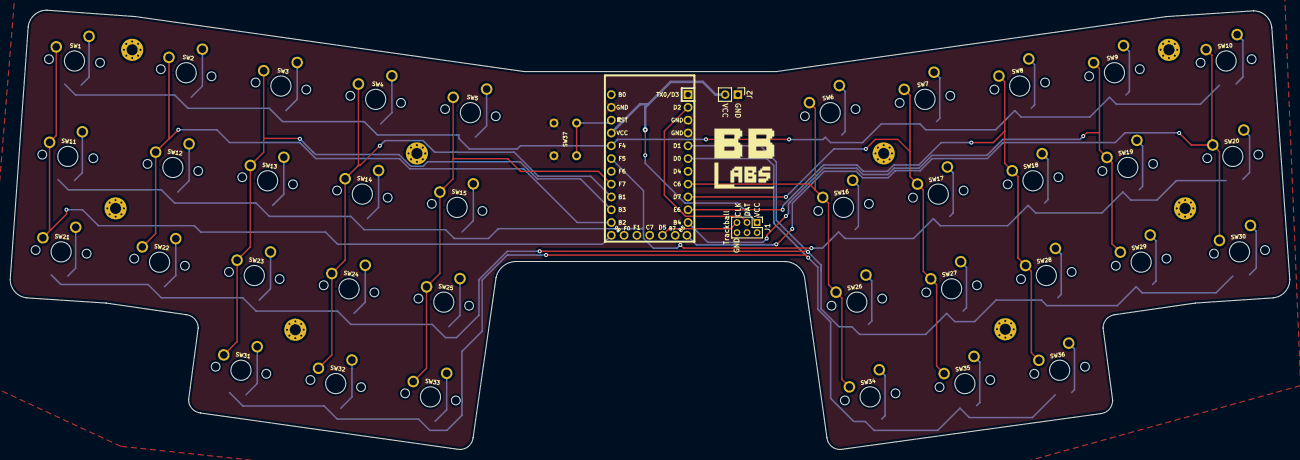
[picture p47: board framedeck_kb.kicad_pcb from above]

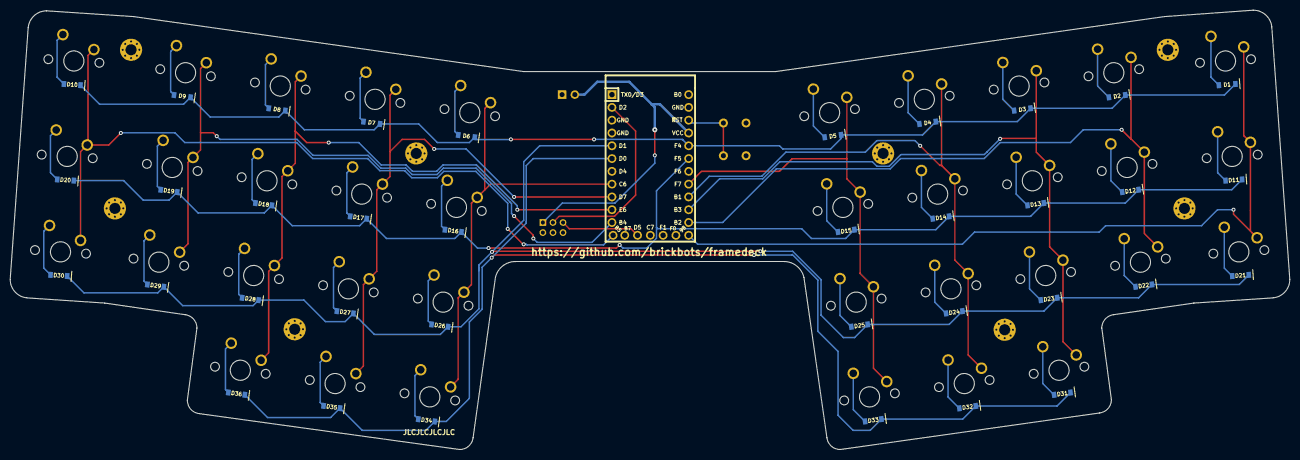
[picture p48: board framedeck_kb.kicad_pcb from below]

Board: 2 copper layers, 254.1 x 87.2 mm, 84 parts (37 on the bottom side), 55 nets.

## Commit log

2022-05-15 Added printed docs
2022-05-16 Typo fix s/obard/board
